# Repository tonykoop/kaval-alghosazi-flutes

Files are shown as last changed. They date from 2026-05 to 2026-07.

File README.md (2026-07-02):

# Kaval + Alghosazi Fipple Flutes

This repository is a prototype design packet for two related long fipple flutes. It is not build-ready for a final instrument until the P0 fipple-head and sound-window correction measurements below are recorded:

- a **Moldavian/Romanian-style fipple kaval** family, including 5-hole, 7-hole, two-piece, and double-drone options;
- a **fipple Alghosazi** family inspired by the Anasazi/Basketmaker long-flute lineage, with an easier fipple head and a rear thumb hole.

The head design intentionally borrows from Tony's `fujara` CAD: the player blows into an end mouth inlet, the air travels through a controlled internal flue, and sound is made at a side **true sound window** and splitting edge. The head is not copied from a commercial maker; it is a Tony-shop fujara/NAF hybrid that can be tuned and rebuilt.

## Build First

Start with these prototypes:

| Prototype | Why |
| --- | --- |
| `KAV-A3-5H` | Best first kaval: published 74 cm precedent, forgiving length, 5-hole pattern. |
| `ALG-AS3-J2` | Best first Alghosazi: published 82 cm two-piece precedent, thumb-hole layout. |
| `P0-FIPPLE-HEAD` | Scrap head tile that proves the mouth inlet, flue, window, and splitting edge before a full body. |

## File Map

| File | Use |
| --- | --- |
| `Kaval-Alghosazi-Design.xlsx` | Parametric workbook: family spec, formulas, hole schedules, fipple inputs. |
| `design.md` | Acoustic model, cultural/source notes, assumptions, and build intent. |
| `family-spec.csv` | Row-per-member design table used by drawing/CAD generators. |
| `hole-schedule.csv` | First-pass hole positions computed from labium-to-foot length (pre-P0; rerun after measured sound-window correction). |
| `bom.csv`, `sourcing.csv`, `cut-list.csv` | Procurement and stock prep. |
| `assembly-manual.md` | Shop sequence from fipple tile through tuning. |
| `docs/p0-fipple-head-measurement.md` | P0 fipple-head build and measurement procedure. |
| `sound-window-correction-log.csv` | Back-solve log for the measured fipple/sound-window correction. |
| `validation-loop.csv` | Prototype validation-loop scaffold with measurement-required gates. |
| `drawings/` | SVG manufacturing drawings and head/joint details. |
| `cad/` | OpenSCAD and SolidWorks starter handoff files. |
| `cnc/` | v4.2 operation plan and setup sheet. |
| `validation.csv` | Tuning and empirical correction log. |
| `capstone-deck.pptx`, `print-packet.pdf`, `site/index.html` | Presentation, shop print, and build-log deliverables. |
| `wolfram/kaval-alghosazi-flutes-wolfram-model.wl` | Existing acoustic model source; pending P0 measured correction. |
| `evolution/` | Evolution-pipeline Stage 0 intake: master manifest, design-intent, revision register (Gate A not yet run). |

## Status

**Status:** L1 concept packet

This is a first-pass engineering packet. Dimensions are parametric and source-backed where possible, but the fipple/sound-window correction is marked as a measured-prototype variable, not a borrowed NAF K2 correction.

Current readiness is `L1_packet`: fabrication drawings and schedules are starter artifacts, while the fipple/head correction, final hole locations, and production readiness remain measurement-required.

V5 migration status: `L1_packet`. Existing SVGs, OpenSCAD, CNC plans, renders, and print/site artifacts are registered in `visual-output-register.csv`; CAD/DXF authority, MCP provenance, sound-window correction, and measured tuning remain pending measurement.

## Attribution

The kaval references come from Moldavian/Romanian shepherd-flute practice; the Alghosazi references point toward Anasazi/Basketmaker flute replicas and contemporary adaptations. This packet is a modern shop design by Tony Koop, built with respect for those lineages and explicit source notes in `sources.md`.

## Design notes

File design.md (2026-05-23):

# Kaval + Alghosazi Fipple Flutes

**Packet ID:** KAV-ALG-FAM-001  
**Family:** open-pipe woodwind / duct-fipple flute  
**Pipeline:** cnc-lathe hybrid: split blank or deep bore, fipple head, lathe rounding, optional two-piece joint  
**Date:** 2026-05-06  
**Done-bar references:** `fujara`, `flutes`, `drone-flutes`, `pistalka`, `transverse-flute`

## Project Intent

Design a buildable family of long fipple kavals and Alghosazi flutes that feel close to the Fujara Flutes references while using Tony's existing fujara/flute workshop logic: parametric dimensions, a controllable fipple sound-window head, split-blank CNC or deep-bore construction, validation tables, and documented tuning loops.

The first physical goal is not a perfect production run. It is a controlled prototype ladder: prove the fipple head, build one A3 5-hole kaval, build one A#3 Alghosazi with a thumb hole, then decide whether the two-piece and double-drone versions deserve full CAD.

## Source And Scope

External reference pages checked:

- Fujara Flutes Kaval page: 5-hole fipple kavals, 7-hole expanded kavals, lengths from about 62-90 cm, and double Kaval/Kavalghoza drone concept.
- Fujara Flutes Alghosazi page: fipple adaptation of Anasazi-style flute, top hole moved to the back as a thumb hole, lengths from about 70-85 cm, and a double-drone option.
- Flutopedia Anasazi tuning notes: used only to justify the Alghosazi starter offset set as an Anasazi-derived primary sequence.

Local source artifacts inspected:

- `fujara/design-table/fujara_equations.md` and SolidWorks dimension extracts for fipple/flue plug geometry.
- `drone-flutes/design.md` and `flutes/skills/parametric-design-table.md` for open-pipe, shop, and validation workflow.
- `pistalka/docs/build-packet/design.md` for a compact fipple-flute build sequence.

## Governing Model

These flutes are modeled as **open-open cylindrical fipple flutes** with a non-NAF fujara-style sound-window end correction.

```text
f = c / (2 * L_eff)
c = 13552 in/s at about 68 F
L_eff = physical_labium_to_foot + foot_end_correction + sound_window_correction
foot_end_correction ~= 0.6 * bore_radius
sound_window_correction = measured prototype value, not Tony's NAF K2 table
```

For first-pass hole placement, the packet uses a proportional open-pipe layout:

```text
x_from_labium = labium_to_foot * 2^(-semitone_offset / 12)
x_from_foot = labium_to_foot - x_from_labium
```

The hole schedule is intentionally a **starter drill schedule**. The builder drills undersized, tunes the root by trimming the foot, then opens each hole upward by careful reaming/undercutting. If a hole goes sharp, the recovery is wax test, bushing, or a rebuilt body.

`family-spec.csv` includes `estimated_sound_window_correction_in`. Positive values mean the fipple/window system or added acoustic path must make the instrument behave longer than the visible labium-to-foot length. Negative values mean the source-observed body length is overlong for the nominal root under a simple open-pipe model; treat those as overlength blanks to trim or as evidence that the commercial key naming may not equal the all-closed root.

The first-pass schedules do not yet include a measured sound-window correction. Back-solve it after P0 with:

```text
L_eff_measured = c / (2 * measured_root_hz)
sound_window_correction = L_eff_measured - labium_to_foot - foot_end_correction
foot_end_correction ~= 0.6 * bore_radius
```

Record the result in `sound-window-correction-log.csv`. Only then update `Kaval-Alghosazi-Design.xlsx`, `family-spec.csv`, and the hole schedules.

## Scale Plans

### 5-Hole Fipple Kaval

The 5-hole kaval follows the published C-reference pitch set:

```text
0, +2, +3, +6, +7, +8 semitones
Example in C: C D D# F# G G#
```

### 7-Hole Fipple Kaval

The expanded kaval adds the two half-step options described by the reference page:

```text
0, +2, +3, +4, +6, +7, +8, +9 semitones
Example in C: C D D# E F# G G# A
```

### Alghosazi

The Alghosazi starter scale uses an Anasazi-derived primary sequence. The top hole is placed on the back as a thumb hole, matching the design note from the reference page.

```text
0, +2, +4, +7, +9, +11, +12 semitones
Example in A#: A# C D F G A A#
```

This is marked as a musical-design assumption. If Tony wants a different Alghosazi mode after listening to examples, change the offsets in `Kaval-Alghosazi-Design.xlsx` and regenerate `hole-schedule.csv`.

## Fujara-Style Fipple Head

The requested head architecture is:

```text
mouth at end -> rectangular inlet -> internal windway/flue -> side true sound window -> splitting edge -> main bore
```

Starter dimensions:

| Feature | Kaval Starter | Alghosazi Starter | Notes |
| --- | ---: | ---: | --- |
| Top end to true window datum | 1.45-1.65 in | 1.65-1.80 in | Adjust for comfort and joint location. |
| Windway height | 0.033-0.045 in | 0.035-0.048 in | Start with removable flue plug trials. |
| Windway width | 0.45-0.55 in | 0.45-0.58 in | About 55-65 percent of bore. |
| Window length | 0.25-0.38 in | 0.28-0.42 in | Widen/lengthen only after tone test. |
| Splitting edge offset KPI | 0.005-0.015 in | 0.005-0.015 in | Borrowed from Tony's fujara canary, not a final law. |
| Plug fit | wax-sealed slip | wax-sealed slip | Removable until final voicing. |

### P0 Measurement Loop

Build `P0-FIPPLE-HEAD` before a full flute body. Use scrap stock or a short half-bore test channel matching the selected bore, cut the end mouth inlet, test removable plug shims at 0.033, 0.038, and 0.045 in, and vary only one window or splitting-edge parameter between trials.

For each speaking trial, log the measured windway height, window length, window width, splitting-edge offset, blow-pressure note, temperature/RH, measured root pitch, and whether the tone chokes, overblows, or stabilizes. The geometry stays inferred until that log exists.

## Two-Piece And Double Options

The two-piece option is a **shop convenience and tuning risk**, not a decorative afterthought. Use it only after a solid prototype speaks well.

- Tenon engagement: 1.25 in minimum.
- Cork compression: fit by sanding; no forced assembly.
- Joint location: avoid placing the joint within 0.75 in of a tone hole.
- Bore step: less than 0.005 in at the joint after final sanding.
- Ferrule: recommended for A/A# bodies and double-flute assemblies.

Double-drone versions are documented in `double-drone-spec.csv` and `drawings/double-drone-layout.svg`. Each side gets its own windway so the melody flute can be played alone and the drone can be tuned independently.

## Family Table

See `family-spec.csv` for the source of truth. The core starter members are:

| Member | Role |
| --- | --- |
| `KAV-A3-5H` | First kaval prototype. |
| `KAV-AS3-7H` | Two-piece expanded kaval prototype. |
| `ALG-AS3-J2` | First Alghosazi prototype. |
| `ALG-A3-J3` | Three-piece Alghosazi joint stress test. |

## Manufacturing Path

Preferred path for the first two prototypes:

1. Make a removable fipple-head test tile from scrap.
2. Record the speaking head settings and back-solve the sound-window correction in `sound-window-correction-log.csv`.
3. Build a split-blank body so the bore, windway, and window are visible and correctable.
4. Glue and turn only after the fipple speaks.
5. Drill holes undersized from a laser/CNC template or V-block setup.
6. Tune root first, then holes from foot upward.
7. Record measurements in `validation.csv` and `validation-loop.csv`, then update the next prototype.

Deep-bore drilling is allowed for later solid-body builds. Use the skill reference `headstock-driven-deep-bore-drilling.md` before attempting a long solid blank.

## Assumptions

- A4 = 440 Hz.
- 68 F speed-of-sound baseline.
- Website lengths are used as precedent dimensions, not guaranteed acoustic formulas.
- Alghosazi tuning is a starter interpretation based on contemporary Anasazi-tuned six-hole practice.
- Tone hole positions ignore final hole-diameter perturbation until measured prototype data exists.
- The fipple head is Tony's derived design and must be validated by physical tests.
- The P0 correction is unknown until measured; do not promote this packet above `L1_packet` from source observations alone.

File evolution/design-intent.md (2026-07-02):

# Design Intent — kaval-alghosazi-flutes rev A

- Master CAD: `cad/kaval_alghosazi_master.scad` (sha256: c42d454dca177201263adffe5e6119c1dd6b02e1e94f62a42d3a19850f0d5d58) + `cad/kaval_alghosazi_body.scad` (sha256: 21786146c1ea73cd9707182d0e88491040a9f89159951d2f006b13d59cee006a), driven by `Kaval-Alghosazi-Design.xlsx` (sha256: e3fb7870a6145c4f49f438ee006fb4e052e1e944b8448978cd7332c4566e9df4)
- Function: A family of long duct/fipple flutes — a Moldavian/Romanian-style fipple kaval (5-hole, 7-hole, two-piece, double-drone variants) and a fipple Alghosazi (Anasazi/Basketmaker-lineage-inspired, rear thumb hole). The head is a Tony-shop fujara/NAF hybrid fipple (end mouth inlet, internal flue, side true sound window + splitting edge), not a copy of a commercial maker's head.
- Environment: hand-held wind instrument; long solid or split-blank wooden body; fipple/flue plug is removable and wax-sealed for voicing iteration.
- Target qty: prototype ladder — one A3 5-hole kaval, then one A#3 Alghosazi with thumb hole, before deciding on two-piece/double-drone variants. Deadline: TBD. Budget/unit ceiling: TBD.

## Critical dimensions (carry tolerances)

| Feature | Nominal | Tolerance | Why critical | Source |
| --- | --- | --- | --- | --- |
| Fipple/sound-window correction | unknown | build P0-FIPPLE-HEAD, compare root prediction vs measured (risks.md Acoustic) | governs all downstream hole positions | sound-window-correction-log.csv (measurement_required) |
| Hole positions (kaval/Alghosazi) | first-pass proportional | drill undersized, record before/after cents per hole (validation.csv) | intonation | hole-schedule.csv / family-spec.csv (measurement_required) |
| Bore-wander tolerance | ≤ 0.050 in exit offset | bore scrap first and measure; switch to split-blank CNC if exceeded (risks.md Structural) | wall integrity | risks.md (measurement_required) |
| Windway height | 0.033-0.045 in (trial range) | voicing iteration on removable plug (bom.csv BOM-002) | attack/tone | bom.csv (measurement_required) |
| Alghosazi thumb hole placement | mark with tape, air-grip test | drill undersized before final (risks.md Ergonomic) | playability/ergonomics | risks.md (measurement_required) |

## Incidental (free for DFM)

- Exterior finish (shellac/oil/wax), ferrule material choice (brass vs. hardwood), cosmetic body shaping outside bore/fipple/hole geometry.

## Must-nots (DFM may never violate)

- Do not finalize hole locations before P0 fipple-head sound-window correction is measured and logged (design.md Project Intent; sound-window-correction-log.csv).
- Do not apply heavy finish to the windway or splitting edge — mask both and recheck attack after cure (risks.md Fit And Finish).
- Do not choose ferrule dimensions before the body OD is turned (risks.md Supply).
- Do not commit to elder/locust stock length/scale without verifying supplier stock first; use ash/maple/cherry for prototypes instead (risks.md Supply).
- Do not drill final tone-hole or thumb-hole diameters directly — undersize and tune/fit-test incrementally (risks.md Acoustic/Ergonomic).

## Material intent

- Preferred: straight-grain elder, locust, ash, maple, cherry, or walnut body blank (bom.csv BOM-001).
- Acceptable subs: ash/maple/cherry for prototypes if elder/locust supply is constrained (risks.md Supply).
- Forbidden: none recorded beyond the prototype-before-final-stock sequencing above.

## Stage status

Stage 0 intake complete 2026-07-01. Gate A (Alpha shop compile) NOT yet run — no concessions logged, nothing presented as shippable. Packet stays L1_packet per README until P0 fipple-head and sound-window correction measurements exist.

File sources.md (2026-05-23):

# Sources And Provenance

## External Pages Checked

- Fujara Flutes Kaval page: https://www.fujaraflutes.com/moldavian-kaval-flutes
- Fujara Flutes Alghosazi page: https://www.fujaraflutes.com/alghosazi
- Flutopedia Native American flute tunings / Anasazi note: https://www.flutopedia.com/naf_tunings.htm

## Local Sources Used

- `../fujara/README.md`
- `../fujara/design-table/fujara_equations.md`
- `../fujara/CAD/fujara-body/G2Fujara_Assembly.SLDASM_dimensions.csv`
- `../drone-flutes/design.md`
- `../flutes/skills/parametric-design-table.md`
- `../pistalka/docs/build-packet/design.md`

## Source-Backed Facts Used

- The kaval reference page presents fipple-style kavals and gives 5-hole and 7-hole pitch sets.
- The same page documents examples in G#, A, B, C and a double Kaval/Kavalghoza drone concept.
- The Alghosazi reference page frames the instrument as an easier fipple adaptation of an Anasazi-style flute and notes the rear thumb-hole idea.
- Tony's fujara CAD records a fipple/flue plug system with narrow windway, removable plug logic, and splitting-edge KPI values.

## Assumptions Needing Prototype Data

- Exact fipple sound-window end correction.
- Measured P0 windway/window/splitting-edge setting that speaks without choking.
- Final hole diameters and undercutting.
- Alghosazi mode preference after listening/playing.
- Joint effect on tuning and response.

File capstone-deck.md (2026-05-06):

# Kaval + Alghosazi Fipple Flutes Capstone
- Musical instrument documentation capstone
- Build packet: kaval-alghosazi-flutes
- Generated: 2026-05-05

---

# Project Intent
- Design a buildable family of long fipple kavals and Alghosazi flutes that feel close to the Fujara Flutes references while using Tony's existing fujara/flute workshop logic: parametric dimensions, a controllable fipple sound-window head, split-blank CNC or deep-bore construction, validation tables, and documented tuning loops.

_Speaker notes:_ Read design.md before committing to dimensions or sourcing decisions.

---

# Physics Model
- These flutes are modeled as **open-open cylindrical fipple flutes** with a non-NAF fujara-style sound-window end correction.

```
f = c / (2 * L_eff)
c = 13552 in/s at about 68 F
L_eff = physical_labium_to_foot + foot_end_correction + sound_window_correction
foot_end_correction ~= 0.6 * bore_radius
sound_window_correction = measured prototype value, not Tony's NAF K2 table
```

```
x_from_labium = labium_to_foot * 2^(-semitone_offset / 12)
x_from_foot = labium_to_foot - x_from_labium
```

_Speaker notes:_ Governing equations extracted verbatim from design.md. Apply empirical corrections (NAF K2, scale offsets) only where the model permits — see references/acoustic-models.md.

---

# How To Use This Packet
- Start with design.md for intent and assumptions.
- Use bom.csv, sourcing.csv, and cut-list.csv before buying or cutting.
- Use drawing-brief.md and CAD/CNC folders before machining.
- Print the packet for shopping, shop work, and validation.

---

# File Map
- design.md: Project intent, catalog metadata, assumptions, and validation plan.
- bom.csv: Starter bill of materials with part categories, quantities, drawing refs, and notes.
- sourcing.csv: Supplier/search tracker with specs, price/date fields, lead time, substitutes, and risks.
- cut-list.csv: Rough/final stock sizes, material, grain/orientation, operations, yield, and offcuts.
- drawing-brief.md: Manufacturing drawing and technical product sketch brief.
- assembly-manual.md: Shop-facing sequence, tools, fixtures, safety, tuning, finishing, and maintenance notes.
- validation.csv: Target/measured values, tolerance, environment, result, and tuning/build action log.
- supplier-rfq.md: Supplier email/request-for-quote starter.

---

# Family Spec

| member_id | instrument | subtype | target_note | target_hz | midi | scale_label | hole_count | hole_offsets_st | bore_id_in | body_od_in | wall_in | total_length_cm | total_length_in | top_to_window_in | labium_to_foot_in | open_pipe_leff_in | estimated_sound_window_correction_in | tuning_delta_interpretation | chamber_to_bore | wood_species | construction | source_basis | done_bar_ref | notes |
| --- | --- | --- | --- | --- | --- | --- | --- | --- | --- | --- | --- | --- | --- | --- | --- | --- | --- | --- | --- | --- | --- | --- | --- | --- |
| KAV-GS3-5H | Fipple Kaval | 5-hole Moldavian/Romanian | G#3 | 207.652 | 56 | Kaval gypsy mode: 0,2,3,6,7,8 semitones | 5 | 2 3 6 7 8 | 0.8750 | 1.3750 | 0.2500 | 79.0 | 31.102 | 1.600 | 29.502 | 32.631 | 3.129 | positive: needs fipple/window end correction or added acoustic length | 33.7 | Locust or elder | solid or split blank; optional two-piece joint | Fujara Flutes observed G# kaval length 79 cm | fujara + flutes + pistalka | Longest 5-hole starter; use as low-voice reference. |
| KAV-A3-5H | Fipple Kaval | 5-hole Moldavian/Romanian | A3 | 220.000 | 57 | Kaval gypsy mode: 0,2,3,6,7,8 semitones | 5 | 2 3 6 7 8 | 0.8750 | 1.3750 | 0.2500 | 74.0 | 29.134 | 1.600 | 27.534 | 30.800 | 3.266 | positive: needs fipple/window end correction or added acoustic length | 31.5 | Elder | two-piece optional hand-cut joint | Fujara Flutes observed A kaval length 74 cm | fujara + flutes + pistalka | Recommended first kaval because length, bore, and hand span are forgiving. |
| KAV-B3-5H | Fipple Kaval | 5-hole Moldavian/Romanian | B3 | 246.942 | 59 | Kaval gypsy mode: 0,2,3,6,7,8 semitones | 5 | 2 3 6 7 8 | 0.8125 | 1.3125 | 0.2500 | 67.0 | 26.378 | 1.500 | 24.878 | 27.440 | 2.562 | positive: needs fipple/window end correction or added acoustic length | 30.6 | Elder | solid split blank | Fujara Flutes observed B kaval length 67 cm | fujara + flutes + pistalka | Compact 5-hole version; tighter fipple tolerances. |
| KAV-C4-5H | Fipple Kaval | 5-hole Moldavian/Romanian | C4 | 261.626 | 60 | Kaval gypsy mode: 0,2,3,6,7,8 semitones | 5 | 2 3 6 7 8 | 0.7500 | 1.2500 | 0.2500 | 62.0 | 24.409 | 1.450 | 22.959 | 25.900 | 2.940 | positive: needs fipple/window end correction or added acoustic length | 30.6 | Elder, maple, or cherry | solid split blank | Fujara Flutes observed C kaval length 62 cm | fujara + flutes + pistalka | Smallest 5-hole kaval; good for fipple/head trials. |
| KAV-A3-7H | Fipple Kaval | 7-hole expanded Moldavian | A3 | 220.000 | 57 | Expanded kaval: 0,2,3,4,6,7,8,9 semitones | 7 | 2 3 4 6 7 8 9 | 0.8750 | 1.4000 | 0.2625 | 90.0 | 35.433 | 1.650 | 33.783 | 30.800 | -2.983 | negative: observed source length is overlong for this nominal root; trim foot or reassess key naming | 38.6 | Elder | solid split blank | Fujara Flutes observed 7-hole A kaval length 90 cm | fujara + flutes + pistalka | Expanded note set; lower holes may be covered with finger bases. |
| KAV-AS3-7H | Fipple Kaval | 7-hole expanded Moldavian | A#3 | 233.082 | 58 | Expanded kaval: 0,2,3,4,6,7,8,9 semitones | 7 | 2 3 4 6 7 8 9 | 0.8750 | 1.4000 | 0.2625 | 85.0 | 33.465 | 1.650 | 31.815 | 29.071 | -2.743 | negative: observed source length is overlong for this nominal root; trim foot or reassess key naming | 36.4 | Dogwood or elder | two-piece optional hand-cut joint | Fujara Flutes observed 7-hole A# kaval length 85 cm | fujara + flutes + pistalka | Good two-piece test because the published example is collapsible. |
| KAV-B3-7H | Fipple Kaval | 7-hole expanded Moldavian | B3 | 246.942 | 59 | Expanded kaval: 0,2,3,4,6,7,8,9 semitones | 7 | 2 3 4 6 7 8 9 | 0.8125 | 1.3125 | 0.2500 | 69.0 | 27.165 | 1.500 | 25.665 | 27.440 | 1.774 | positive: needs fipple/window end correction or added acoustic length | 31.6 | Elder | solid split blank | Fujara Flutes observed 7-hole B kaval length 69 cm | fujara + flutes + pistalka | Compact 7-hole version; validate hand position before final hole diameters. |
| ALG-AS3-J2 | Fipple Alghosazi | Anasazi-derived with thumb hole | A#3 | 233.082 | 58 | Anasazi-derived: 0,2,4,7,9,11,12 semitones | 6 | 2 4 7 9 11 12 | 0.8750 | 1.3750 | 0.2500 | 82.0 | 32.283 | 1.800 | 30.483 | 29.071 | -1.412 | negative: observed source length is overlong for this nominal root; trim foot or reassess key naming | 34.8 | Ash | two-piece hand-cut joint | Fujara Flutes observed A# Alghosazi length 82 cm | fujara + flutes + pistalka | Recommended first Alghosazi; published example uses a collapsible joint. |
| ALG-AS3-SOLID | Fipple Alghosazi | Anasazi-derived with thumb hole | A#3 | 233.082 | 58 | Anasazi-derived: 0,2,4,7,9,11,12 semitones | 6 | 2 4 7 9 11 12 | 0.8750 | 1.3750 | 0.2500 | 85.0 | 33.465 | 1.800 | 31.665 | 29.071 | -2.593 | negative: observed source length is overlong for this nominal root; trim foot or reassess key naming | 36.2 | Locust | solid split blank | Fujara Flutes observed solid A# Alghosazi length 85 cm | fujara + flutes + pistalka | Solid-body alternate for comparing joint vs no-joint response. |
| ALG-A3-J3 | Fipple Alghosazi | Anasazi-derived with thumb hole | A3 | 220.000 | 57 | Anasazi-derived: 0,2,4,7,9,11,12 semitones | 6 | 2 4 7 9 11 12 | 0.8750 | 1.3750 | 0.2500 | 73.0 | 28.740 | 1.750 | 26.990 | 30.800 | 3.810 | positive: needs fipple/window end correction or added acoustic length | 30.8 | Oak | three-piece hand-cut joint | Fujara Flutes observed A Alghosazi length 73 cm | fujara + flutes + pistalka | Use as the modular joint stress test. |
| ALG-B3-SOLID | Fipple Alghosazi | Anasazi-derived with thumb hole | B3 | 246.942 | 59 | Anasazi-derived: 0,2,4,7,9,11,12 semitones | 6 | 2 4 7 9 11 12 | 0.8125 | 1.3125 | 0.2500 | 70.0 | 27.559 | 1.650 | 25.909 | 27.440 | 1.531 | positive: needs fipple/window end correction or added acoustic length | 31.9 | Elder or maple | solid split blank | Fujara Flutes observed B Alghosazi length 70 cm | fujara + flutes + pistalka | Compact Alghosazi; top thumb hole needs ergonomic mockup. |

_Speaker notes:_ Sizes scale via the master scale factor; tuning targets are first-order Helmholtz/cantilever predictions to be empirically corrected per prototype.

---

# Build Workflow
- Design and assumptions
- Source materials and hardware
- Prepare stock, fixtures, and CNC/laser/lathe setup
- Assemble, tune, finish, and validate

---

# Sourcing And BOM
- BOM gives part categories and drawing references.
- Sourcing tracks search terms, supplier candidates, price/date, lead time, substitutions.
- Visual BOM brief turns the parts list into a presentation-ready image board.

---

# Shop Packet
- Cut list for lumber/sheet/blank planning.
- Assembly manual for away-from-keyboard work.
- Validation sheet for measured dimensions, tuning, pass/fail checks.

---

# Drawings, CAD, CNC
- drawing-brief.md defines required views, dimensions, datums, sketch intent.
- cad/ holds models and design tables.
- cnc/ holds CAM, toolpaths, setup sheets, dry-run notes.
- drawings/ holds PDFs, SVGs, DXFs, drawing exports.






---

# Images And Screenshots
- images/hero.png

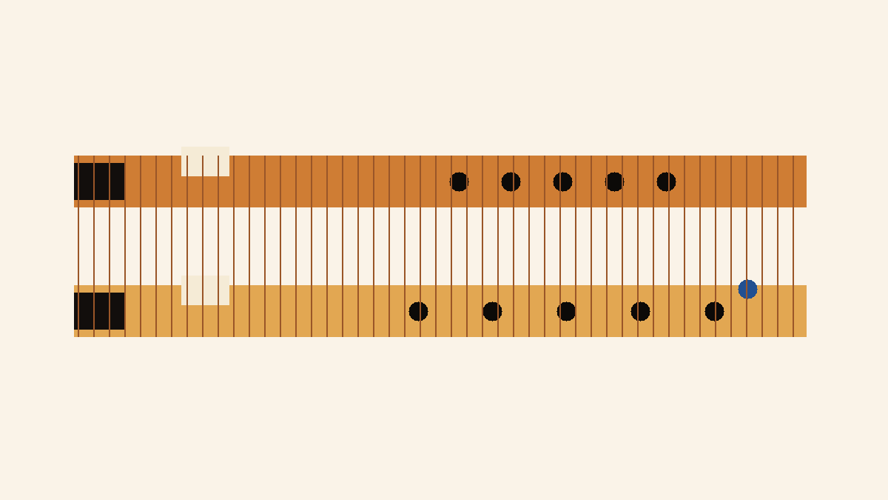
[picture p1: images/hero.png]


---

# Validation Plan
- A4 = 440 Hz reference check.
- Tuning targets logged in validation.csv.
- Critical dimensions verified against design sheet and CAD.
- Photos and revision notes after each major step.

---

# Open Risks / Decisions
- TBDs in design sheet and BOM.
- Supplier price/availability not yet verified.
- Generated images marked as concept placeholders.
- Empirical corrections await measured prototype data.

---

# Next Actions
- Replace TBDs with measured/source-backed values.
- Verify live supplier price and availability before buying.
- Export final drawings and visual BOM images.
- Regenerate this deck and print packet after final edits.

---

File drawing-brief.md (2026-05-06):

# Drawing Brief

## Required Views

- Family overview: each member as a scaled open-pipe body with bore ID and total length.
- Hole layout: kaval and Alghosazi separate, measured from labium and from foot.
- Fipple head section: end mouth inlet, windway, flue plug, true sound window, splitting edge, bore.
- Two-piece joint section: tenon, socket, cork wrap, ferrule/collar, bore continuity.
- Double-drone layout: two bores, independent windways, melody side, drone side, thumb vent.

## Datums

- Datum A: labium/splitting-edge plane.
- Datum B: tuned foot end.
- Datum C: bore centerline.
- Datum D: back thumb-hole centerline for Alghosazi.

## Tolerances

- Bore ID: +/-0.005 in after reaming/lapping.
- Hole center: +/-0.020 in before tuning; final pitch matters more than nominal center.
- Windway height: +/-0.002 in once a plug speaks.
- Joint bore step: less than 0.005 in.
- Noncritical exterior: +/-0.030 in.

## Drawing Outputs

Generated SVGs live in `drawings/`. Build-critical dimensions come from `Kaval-Alghosazi-Design.xlsx`, `family-spec.csv`, and `hole-schedule.csv`, not from raster images.

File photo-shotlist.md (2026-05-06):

# Photo Shotlist

Follow the repo-level photo pipeline style: real process photos replace concept placeholders as soon as shop work begins.

## P0 Fipple Head

- End mouth inlet before plug install.
- Removable flue plugs with shim labels.
- Side true sound window and splitting edge closeup.
- Tuner screenshot or phone photo during first tone.

## P1 Bodies

- Blank selection with grain orientation marked.
- Split blank or deep-bore setup.
- Routed/bored bore before glue-up.
- Hole template wrapped around body.
- First drilled undersized hole.
- Final tuned flute full length.

## Jointed/Double Options

- Tenon/socket before cork.
- Cork/ferrule fit closeup.
- Double-body temporary clamp test.
- Independent windways at the mouth end.

## Finished Portfolio

- Kaval and Alghosazi side by side.
- Player hand reach shot.
- Fipple head detail.
- Validation/tuning bench shot.

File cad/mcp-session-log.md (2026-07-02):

# Kaval + Alghosazi Flutes MCP Session Log

Current status: no MCP, CAD, DXF, render, CAM, or measurement sessions were run
or verified in this V5 migration lane.

This log is a provenance stub for future V5 work. Existing packet content is
grounded in `README.md`, `design.md`, `family-spec.csv`, the hole schedules,
`docs/p0-fipple-head-measurement.md`, `docs/sound-window-correction-model.md`,
and the validation logs. This file does not claim that native CAD, measured
sound-window correction, measured tuning, or CAM-ready toolpaths already exist.

| timestamp_utc | tool | session_id | artifact | parent_artifact | role | authority | notes |
| --- | --- | --- | --- | --- | --- | --- | --- |
| TBD | SolidWorks MCP | TBD | native CAD layout | `cad/SolidWorks-MasterLayout-Plan.md`; `cad/design-table-inputs.csv` | native CAD master | pending_measurement | Future session must preserve fipple-head and hole-position measurement gates. |
| TBD | OpenSCAD review | TBD | `cad/kaval_alghosazi_master.scad` | `family-spec.csv`; `hole-schedule.csv`; `cad/design-table-inputs.csv` | parametric CAD starter | pending_measurement | Existing OpenSCAD is not native CAD or CAM authority. |
| TBD | DXF export | TBD | hole and body templates under `drawings/` | reviewed CAD/table source | fabrication template | pending_measurement | Future DXF exports must wait for measured sound-window correction and reviewed hole schedules. |
| TBD | CNC/CAM review | TBD | shop toolpaths | `cnc/cnc-plan.json`; reviewed CAD/DXF | CAM setup | pending_measurement | Current CNC files are operation plans only, not G-code or release-ready toolpaths. |
| TBD | Wolfram/acoustic analysis | TBD | corrected acoustic model | `docs/sound-window-correction-model.md`; measured `sound-window-correction-log.csv` | acoustic validation | pending_measurement | Model estimates are not cut authority until P0 measurement exists. |
| TBD | Camera/render tool | TBD | `images/hero.png` or replacement render | reviewed CAD or concept brief | visual support | concept_only | Visuals must not control fipple geometry, bore, hole centers, or tuning. |
| 2026-07-01 | claude-code (Fable 5) + OpenSCAD CLI | fable-v5-refresh-2026-07-01 | `cad/kaval_alghosazi_master.scad`; `cad/kaval_alghosazi_body.scad` | `family-spec.csv`; `hole-schedule.csv`; `cad/design-table-inputs.csv` | packet_refresh (render check only) | pending_measurement | Both existing OpenSCAD starters kept as-is (no rewrite). Render check: pass for both (openscad -o STL, exit 0). README status line normalized from prose-only "## Status" section to a proper `**Status:**` line (L1 concept packet, no level change); evolution/ Stage 0 intake added. |

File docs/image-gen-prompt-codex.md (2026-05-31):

# Image Generation Prompt

Concept visualization only. Do not treat generated images as dimensional, tuning, CAD, DXF, or fabrication authority.

## Hero Prompt

Photorealistic studio product photograph of two related long fipple flute prototypes: a Moldavian/Romanian-style fipple kaval with five front holes and a fipple Alghosazi with six holes plus a rear thumb-hole indication, both using Tony's fujara/NAF hybrid fipple head with an end mouth inlet, internal windway, side true sound window, and splitting edge. Warm straight-grain wood, optional two-piece joint on one body, clean studio background, soft directional lighting, three-quarter product angle, about a 50mm lens, high detail.

## In-Context Prompt

Photorealistic workshop scene showing the kaval and Alghosazi prototypes beside a removable P0 fipple-head test tile, plug shims, a tuner, and hole templates. Natural light, tidy bench, the long bodies and side sound-window heads visible, environmental storytelling about measuring the sound-window correction before full production.

## Detail/Macro Prompt

Macro close-up of the fujara-style fipple head used on the kaval/Alghosazi: end mouth inlet, smooth internal windway exit, side true sound window, crisp splitting edge, removable plug fit, wax-sealed trial shims nearby, warm wood grain, photorealistic high detail.

## Negative / Avoid

Avoid logos, watermarks, readable text, recorder beak mouthpieces, generic panpipes, impossible hole patterns, extra drones unless clearly separate, distorted hands, and false measured labels.

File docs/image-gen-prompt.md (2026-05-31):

# Image-Gen Prompts

Concept image only; not fabrication authority. Do not include cut-ready dimensions, hole locations, or toolpaths.

## Hero Prompt

A long slender wooden fipple flute presented as a finished physical instrument, laid at a clean 3/4 product-photography angle on a neutral light-gray studio sweep. It is a turned cylindrical open-pipe woodwind roughly two and a half feet long, lathe-rounded with a smooth satin oil finish that lets the warm grain of a pale European hardwood (elder or maple) show through. The recognizable feature is a fujara-style fipple head at the top end: the player blows into an end mouth inlet, and a side true sound window with a crisp splitting edge is cut into the body a short way down from the cap, the signature mark of this duct-fipple design. A short row of round tone holes runs along the front of the lower body. The bore is a single clean cylinder of even diameter. Soft directional studio light rakes from upper left, modeling the cylindrical surface and casting a soft shadow. ~50mm lens, shallow but controlled depth of field, photorealistic, high detail, no text labels, no maker marks.

## In-Context Prompt

The kaval and Alghosazi fipple flutes staged on a maker's workbench in a small woodworking shop, soft natural window light from the side, with curls of wood shaving, a few hand tools, and a length of split-blank stock blurred in the background. One flute rests on a felt-lined cradle while a second leans against a vise; the warm satin-oiled hardwood bodies glow against the muted shop tones. Environmental storytelling of a one-off prototype build, shallow depth of field, concept visualization only, photorealistic, no text or signage.

## Detail Prompt

Macro close-up of the fujara-style fipple head: the end mouth inlet at the very top, the turned cap and internal windway implied, and just below it on the side of the body the rectangular true sound window with its sharp splitting edge where the air column is excited. Raking low-angle light grazes across the window opening and splitting edge to reveal the crisp cut and the fine grain and satin finish of the pale hardwood. Extremely high detail on the wood texture and the clean edge geometry, no measurements, no callout lines, no text.

## Negative / Avoid

No text, logos, watermarks, or fake maker marks; no dimension callouts, leader lines, or measurement numbers; no impossible or fantasy mechanisms, no metal keywork (these are open-hole flutes); anatomically plausible hands if a player is shown.

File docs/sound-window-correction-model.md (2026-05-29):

# Sound-Window Correction — Acoustic Back-Solve Model

Status: L1 model estimate. No physical P0 measurement has been performed yet.
All corrections below are first-order analytical values. The P0 fipple-head
measurement must be completed before any hole position is considered authoritative.

## Purpose

The side sound-window and splitting edge of a fipple flute create an acoustic
end-correction that shifts the effective length of the air column away from the
physical labium-to-foot distance. This correction must be measured at P0 and
applied to the hole-schedule before drilling.

## Model

For an open-open cylindrical fipple flute, the effective length is:

```
L_eff = c / (2 × f_root)
```

where:
- `c` = speed of sound at lab conditions ≈ 345,400 mm/s at 22 °C (13,598 in/s)
- `f_root` = measured root pitch in Hz (tuner capture at P0)

The total effective length is composed of:

```
L_eff = labium_to_foot + sound_window_correction + foot_end_correction
```

Rearranging to back-solve the sound-window correction:

```
sound_window_correction = L_eff - labium_to_foot - foot_end_correction
```

The foot end-correction for an unflanged open end:

```
foot_end_correction ≈ 0.6 × bore_radius
```

## Model Estimates (pending P0 measurement)

These are **pre-P0 estimates only**. Do not use for cutting. Record the
measured back-solve in `sound-window-correction-log.csv` after the P0 build.

Sound speed at 22 °C / 345.4 m/s = 13,598 in/s = 345,400 mm/s.

### KAV-A3-5H (kaval, A3 root, 5-hole)

| Parameter | Value | Source |
| --- | --- | --- |
| Target root | A3 = 220.000 Hz | family-spec.csv |
| Bore ID | 0.875 in = 22.23 mm | Kaval-Alghosazi-Design.xlsx |
| Bore radius | 11.11 mm | derived |
| L_eff at 220 Hz | 345,400 / (2 × 220) = 785.0 mm | model estimate |
| Foot end-correction | 0.6 × 11.11 = 6.7 mm | standard approximation |
| Labium-to-foot (nominal) | ~735 mm | workbook estimate — measurement required |
| **Model sound-window correction** | **785.0 − 735 − 6.7 ≈ +43 mm** | **model estimate — pending P0** |

**Acoustic honesty caveat:** The labium-to-foot distance is a workbook estimate
from source references. The actual P0-measured value may differ by ±10 mm or
more depending on fipple-head geometry and plug setting. The model correction
of +43 mm is a **starting reference only**, not a dimensional authority.

### ALG-AS3-J2 (alghosazi, A#3 root, two-piece, 6-hole)

| Parameter | Value | Source |
| --- | --- | --- |
| Target root | A#3 = 233.082 Hz | family-spec.csv |
| Bore ID | 0.875 in = 22.23 mm | Kaval-Alghosazi-Design.xlsx |
| Bore radius | 11.11 mm | derived |
| L_eff at 233.082 Hz | 345,400 / (2 × 233.082) = 741.2 mm | model estimate |
| Foot end-correction | 0.6 × 11.11 = 6.7 mm | standard approximation |
| Labium-to-foot (nominal) | ~690 mm | workbook estimate — measurement required |
| **Model sound-window correction** | **741.2 − 690 − 6.7 ≈ +44.5 mm** | **model estimate — pending P0** |

**Acoustic honesty caveat:** Same as KAV-A3-5H above. All values are
analytical estimates; the P0 measurement log drives actual hole positions.

## Hole-Schedule Update Rule

If the back-solved P0 correction shifts any hole center by more than 2.5 mm
(0.100 in), regenerate the hole-schedule(s) from the corrected labium-to-foot
before marking any column `measured`.

The `effective_length_correction_mm` column in `hole-schedule.csv`,
`kaval-hole-schedule.csv`, and `alghosazi-hole-schedule.csv` holds the
correction applied for the row's geometry. Until P0 is complete, all values
in that column are `pending_measurement`.

## Reference

- Fletcher and Rossing, *Physics of Musical Instruments*, §16.2 — end corrections
  for open cylindrical pipes.
- Benade, *Fundamentals of Musical Acoustics*, §21.2 — fipple and labium
  end-correction discussion.
- `docs/p0-fipple-head-measurement.md` — measurement procedure and P0 pass criteria.
- `sound-window-correction-log.csv` — back-solve log to fill after P0 build.

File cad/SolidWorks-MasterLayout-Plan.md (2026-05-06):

# SolidWorks Master Layout Plan

## Master Sketch

- `g_body_L_total`
- `g_labium_to_foot`
- `g_top_to_window`
- `g_bore_ID`
- `g_body_OD`
- `g_wall`
- `g_windway_height`
- `g_windway_width`
- `g_window_length`
- `g_window_width`
- `g_splitting_edge_offset`
- `g_joint_tenon_length`
- `g_joint_cork_allowance`

## Configurations

Use `cad/design-table-inputs.csv` as the row-per-member design table. Each configuration should suppress or enable:

- 5-hole vs 7-hole pattern.
- Alghosazi back thumb hole.
- Solid vs jointed body.
- Double-drone assembly reference geometry.

## Critical CAD Checks

- Bore centerline stays continuous across joint.
- Hole center coordinates match `hole-schedule.csv`.
- Windway height is equation-driven, not a sketch accident.
- Splitting-edge offset is measured as a driven KPI.

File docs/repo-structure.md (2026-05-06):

# Repository Structure

This is a root-level project-repo packet with build-packet artifacts at the top level, matching Tony's existing `drone-flutes`, `gemshorn`, and `transverse-flute` style.

Generated directories:

- `cad/` - OpenSCAD, SolidWorks design table inputs, global variables.
- `cnc/` - v4.2 pre-CAM operation plan.
- `data/` - guided intake and source observations.
- `drawings/` - manufacturing SVG drawings.
- `images/` - concept placeholder and future build photos.
- `site/` - static build-log site.
- `wolfram/` - generated Wolfram model package.

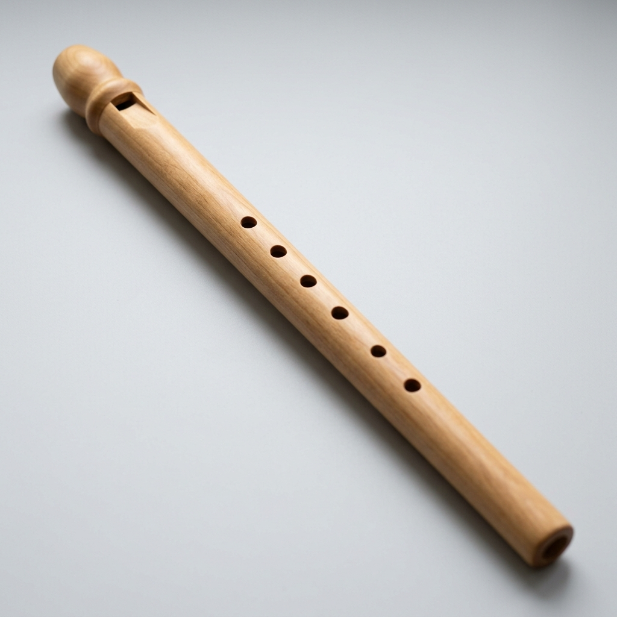
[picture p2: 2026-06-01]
images/hero-render.png

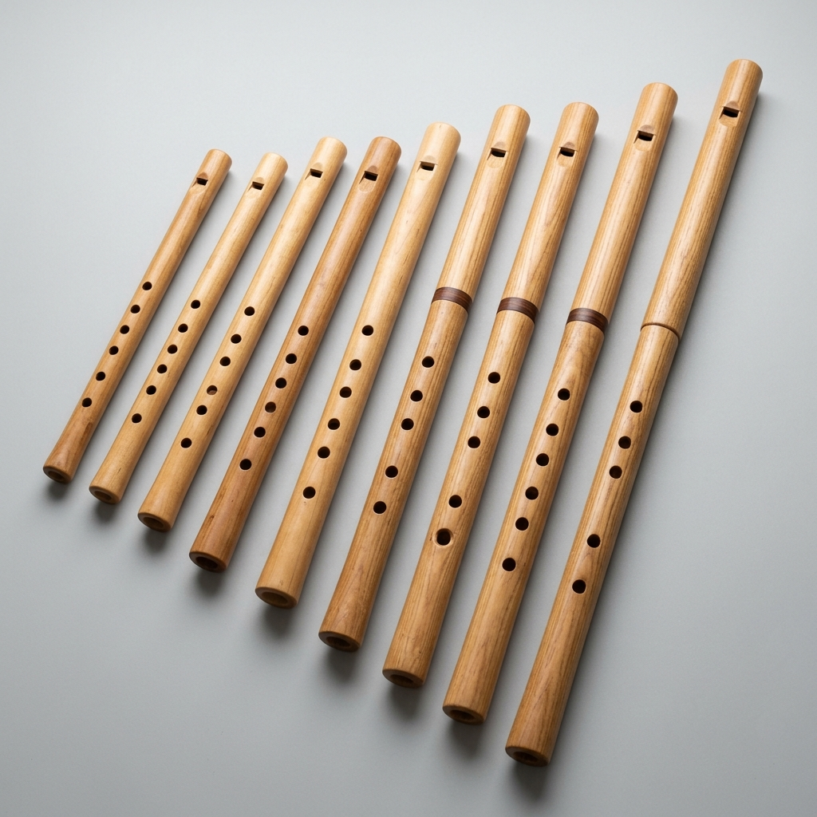
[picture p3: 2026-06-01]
images/family-group.png

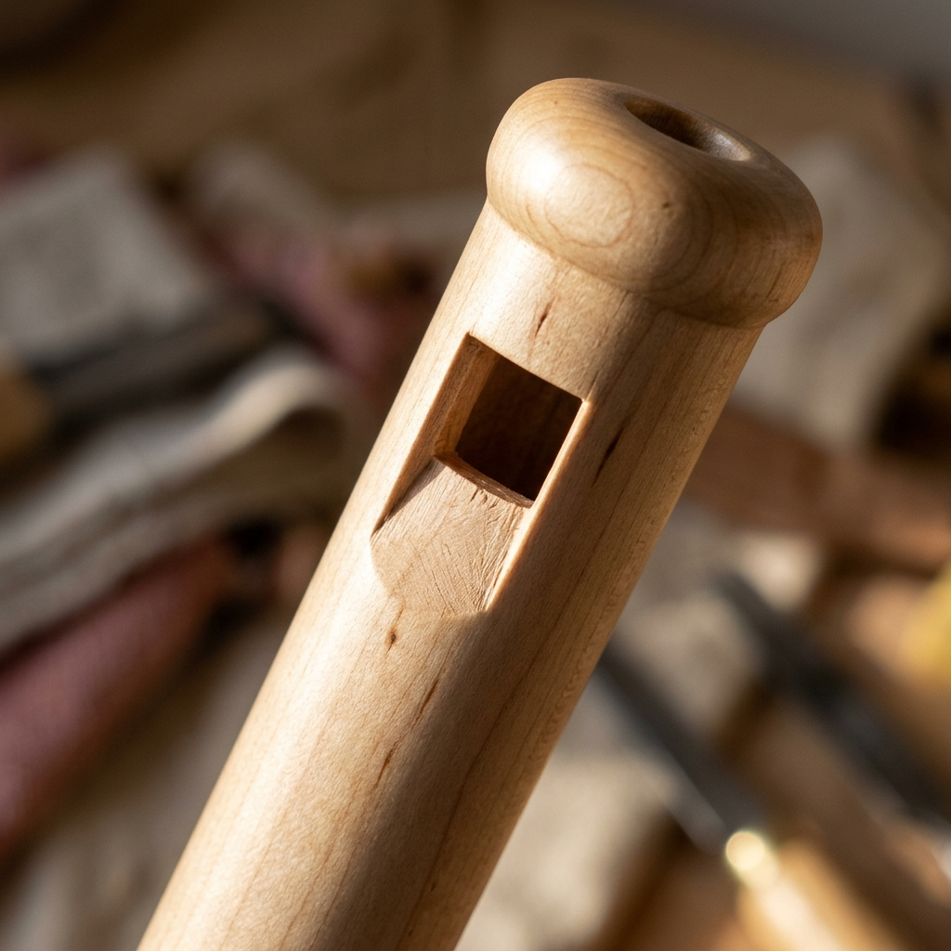
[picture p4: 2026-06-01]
images/macro/fipple-sound-window.png

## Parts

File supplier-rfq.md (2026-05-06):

# Supplier RFQ Draft

Subject: Quote request for straight-grain woodwind blanks and optional ferrule stock

Hello,

I am building a small run of long fipple flutes and need stable straight-grain blanks suitable for bored woodwind bodies.

Please quote the following:

- 4 to 8 blanks, 1.25 to 1.50 in square or round, 30 to 38 in long.
- Species options: elder, locust, ash, maple, cherry, walnut, or similar stable hardwood.
- Moisture content and straightness/grain-runout information.
- Any longer stock suitable for 85-90 cm flute bodies.
- Optional thin-wall brass tube or hardwood ferrule stock around 1.25 to 1.40 in ID/OD range.

The blanks will be drilled or split-routed along the long axis, then turned and tuned, so straight grain and low checking risk matter more than figure.

Please include unit price, volume price, lead time, shipping estimate, and any recommended substitutes.

Thank you,
Tony Koop

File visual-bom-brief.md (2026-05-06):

# Visual BOM Brief

Create one image-forward BOM plate with:

- hero view of a kaval, an Alghosazi, and the fipple-head section;
- item rows for body blank, fipple plug, cork/ferrule, drilling template, finish, and validation tools;
- callouts that distinguish make vs buy parts;
- source status labels: verified price, spec only, or shop stock.

Image sources:

- Use real shop photos after P0/P1 prototypes exist.
- Until then, use `images/hero.png` and the SVG drawings as concept placeholders.
- Do not use vendor or Fujara Flutes photos directly in the BOM without permission.

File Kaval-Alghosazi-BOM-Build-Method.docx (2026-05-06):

# Kaval + Alghosazi Fipple Flutes Capstone Print Packet

Generated: 2026-05-05 Packet folder: /mnt/c/Users/Tony/Documents/GitHub/kaval-alghosazi-flutes

## File Map

File | Purpose
design.md | Project intent, catalog metadata, assumptions, and validation plan.
bom.csv | Starter bill of materials with part categories, quantities, drawing refs, and notes.
sourcing.csv | Supplier/search tracker with specs, price/date fields, lead time, substitutes, and risks.
cut-list.csv | Rough/final stock sizes, material, grain/orientation, operations, yield, and offcuts.
drawing-brief.md | Manufacturing drawing and technical product sketch brief.
assembly-manual.md | Shop-facing sequence, tools, fixtures, safety, tuning, finishing, and maintenance notes.
validation.csv | Target/measured values, tolerance, environment, result, and tuning/build action log.
supplier-rfq.md | Supplier email/request-for-quote starter.
visual-bom-brief.md | Art direction for an image-forward visual BOM.
wolfram-starter.wl | Wolfram starter for physics, optimization, visualization, and validation.
README.md | Project artifact.
alghosazi-hole-schedule.csv | Project artifact.
double-drone-spec.csv | Project artifact.
family-spec.csv | Project artifact.
hole-schedule.csv | Project artifact.
kaval-hole-schedule.csv | Project artifact.
photo-shotlist.md | Project artifact.
risks.md | Project artifact.
sources.md | Project artifact.

## design.md

Project intent, catalog metadata, assumptions, and validation plan.

# Kaval + Alghosazi Fipple Flutes

Packet ID: KAV-ALG-FAM-001
Family: open-pipe woodwind / duct-fipple flute
Pipeline: cnc-lathe hybrid: split blank or deep bore, fipple head, lathe rounding, optional two-piece joint
Date: 2026-05-06
Done-bar references: fujara, flutes, drone-flutes, pistalka, transverse-flute

## Project Intent

Design a buildable family of long fipple kavals and Alghosazi flutes that feel close to the Fujara Flutes references while using Tony’s existing fujara/flute workshop logic: parametric dimensions, a controllable fipple sound-window head, split-blank CNC or deep-bore construction, validation tables, and documented tuning loops.

The first physical goal is not a perfect production run. It is a controlled prototype ladder: prove the fipple head, build one A3 5-hole kaval, build one A#3 Alghosazi with a thumb hole, then decide whether the two-piece and double-drone versions deserve full CAD.

## Source And Scope

External reference pages checked:

- Fujara Flutes Kaval page: 5-hole fipple kavals, 7-hole expanded kavals, lengths from about 62-90 cm, and double Kaval/Kavalghoza drone concept.
- Fujara Flutes Alghosazi page: fipple adaptation of Anasazi-style flute, top hole moved to the back as a thumb hole, lengths from about 70-85 cm, and a double-drone option.
- Flutopedia Anasazi tuning notes: used only to justify the Alghosazi starter offset set as an Anasazi-derived primary sequence.

Local source artifacts inspected:

- fujara/design-table/fujara_equations.md and SolidWorks dimension extracts for fipple/flue plug geometry.
- drone-flutes/design.md and flutes/skills/parametric-design-table.md for open-pipe, shop, and validation workflow.
- pistalka/docs/build-packet/design.md for a compact fipple-flute build sequence.

## Governing Model

These flutes are modeled as open-open cylindrical fipple flutes with a non-NAF fujara-style sound-window end correction.

f = c / (2 * L_eff)
c = 13552 in/s at about 68 F
L_eff = physical_labium_to_foot + foot_end_correction + sound_window_correction
foot_end_correction ~= 0.6 * bore_radius
sound_window_correction = measured prototype value, not Tony's NAF K2 table

For first-pass hole placement, the packet uses a proportional open-pipe layout:

x_from_labium = labium_to_foot * 2^(-semitone_offset / 12)
x_from_foot = labium_to_foot - x_from_labium

The hole schedule is intentionally a starter drill schedule. The builder drills undersized, tunes the root by trimming the foot, then opens each hole upward by careful reaming/undercutting. If a hole goes sharp, the recovery is wax test, bushing, or a rebuilt body.

family-spec.csv includes estimated_sound_window_correction_in. Positive values mean the fipple/window system or added acoustic path must make the instrument behave longer than the visible labium-to-foot length. Negative values mean the source-observed body length is overlong for the nominal root under a simple open-pipe model; treat those as overlength blanks to trim or as evidence that the commercial key naming may not equal the all-closed root.

## Scale Plans

### 5-Hole Fipple Kaval

The 5-hole kaval follows the published C-reference pitch set:

0, +2, +3, +6, +7, +8 semitones
Example in C: C D D# F# G G#

### 7-Hole Fipple Kaval

The expanded kaval adds the two half-step options described by the reference page:

0, +2, +3, +4, +6, +7, +8, +9 semitones
Example in C: C D D# E F# G G# A

### Alghosazi

The Alghosazi starter scale uses an Anasazi-derived primary sequence. The top hole is placed on the back as a thumb hole, matching the design note from the reference page.

0, +2, +4, +7, +9, +11, +12 semitones
Example in A#: A# C D F G A A#

This is marked as a musical-design assumption. If Tony wants a different Alghosazi mode after listening to examples, change the offsets in Kaval-Alghosazi-Design.xlsx and regenerate hole-schedule.csv.

## Fujara-Style Fipple Head

The requested head architecture is:

mouth at end -> rectangular inlet -> internal windway/flue -> side true sound window -> splitting edge -> main bore

Starter dimensions:

Feature | Kaval Starter | Alghosazi Starter | Notes
Top end to true window datum | 1.45-1.65 in | 1.65-1.80 in | Adjust for comfort and joint location.
Windway height | 0.033-0.045 in | 0.035-0.048 in | Start with removable flue plug trials.
Windway width | 0.45-0.55 in | 0.45-0.58 in | About 55-65 percent of bore.
Window length | 0.25-0.38 in | 0.28-0.42 in | Widen/lengthen only after tone test.
Splitting edge offset KPI | 0.005-0.015 in | 0.005-0.015 in | Borrowed from Tony’s fujara canary, not a final law.
Plug fit | wax-sealed slip | wax-sealed slip | Removable until final voicing.

## Two-Piece And Double Options

The two-piece option is a shop convenience and tuning risk, not a decorative afterthought. Use it only after a solid prototype speaks well.

- Tenon engagement: 1.25 in minimum.
- Cork compression: fit by sanding; no forced assembly.
- Joint location: avoid placing the joint within 0.75 in of a tone hole.
- Bore step: less than 0.005 in at the joint after final sanding.
- Ferrule: recommended for A/A# bodies and double-flute assemblies.

Double-drone versions are documented in double-drone-spec.csv and drawings/double-drone-layout.svg. Each side gets its own windway so the melody flute can be played alone and the drone can be tuned independently.

## Family Table

See family-spec.csv for the source of truth. The core starter members are:

Member | Role
KAV-A3-5H | First kaval prototype.
KAV-AS3-7H | Two-piece expanded kaval prototype.
ALG-AS3-J2 | First Alghosazi prototype.
ALG-A3-J3 | Three-piece Alghosazi joint stress test.

## Manufacturing Path

Preferred path for the first two prototypes:

1. Make a removable fipple-head test tile from scrap.
2. Build a split-blank body so the bore, windway, and window are visible and correctable.
3. Glue and turn only after the fipple speaks.
4. Drill holes undersized from a laser/CNC template or V-block setup.
5. Tune root first, then holes from foot upward.
6. Record measurements in validation.csv and update the next prototype.

Deep-bore drilling is allowed for later solid-body builds. Use the skill reference headstock-driven-deep-bore-drilling.md before attempting a long solid blank.

## Assumptions

- A4 = 440 Hz.
- 68 F speed-of-sound baseline.
- Website lengths are used as precedent dimensions, not guaranteed acoustic formulas.
- Alghosazi tuning is a starter interpretation based on contemporary Anasazi-tuned six-hole practice.
- Tone hole positions ignore final hole-diameter perturbation until measured prototype data exists.
- The fipple head is Tony’s derived design and must be validated by physical tests.

## bom.csv

Starter bill of materials with part categories, quantities, drawing refs, and notes.

item | assembly | part | qty | spec | make_buy | est_cost_usd | source_status | drawing_ref | notes
BOM-001 | all | Primary body blank | 1 per flute | Straight-grain elder, locust, ash, maple, cherry, or walnut; length per family-spec plus 2 in trim | buy | 25-90 | spec only | drawings/*-body.svg | Avoid runout through tone holes and joint tenons.
BOM-002 | head | Removable fipple/flue plug | 1 plus 2 test plugs | Hard maple, pear, or dense straight-grain scrap; 0.033-0.045 in windway height trials | make | 5 | shop scrap ok | drawings/fipple-head-section.svg | Wax-sealed removable plug makes voicing iteration survivable.
BOM-003 | joint | Cork sheet or natural cork rings | 1 strip per joint | 1/32 to 1/16 in cork, sanded to airtight slip fit | buy | 8-15 | verify before purchase | drawings/two-piece-joint.svg | Use only on removable joints; permanent split bodies use glue.
BOM-004 | joint | Brass or hardwood ferrule sleeve | optional | Thin brass tube or hardwood collar sized to body OD | buy/make | 10-25 | verify diameter | drawings/two-piece-joint.svg | Recommended for long A/A# bodies and double-flute assemblies.
BOM-005 | finish | Exterior finish | 1 | Shellac, polymerized oil, or oil/wax; keep windway and bore lightly sealed only after tuning | buy | 10-30 | shop stock likely | assembly-manual.md | No heavy finish on splitting edge.
BOM-006 | fixture | V-block and drilling template stock | 1 set | MDF/plywood V-block, laser-cut paper/acrylic hole templates, 1/4 in dowel pins | make | 10-20 | shop stock likely | cnc/setup-sheet.md | Template holes should be undersized pilots.
BOM-007 | validation | Tuning/measurement kit | 1 | Chromatic tuner, thermometer/hygrometer, calipers, small round files, recording device | use shop kit | 0-60 | existing kit likely | validation.csv | Record temperature with every tuning pass.

## sourcing.csv

Supplier/search tracker with specs, price/date fields, lead time, substitutes, and risks.

component | required_spec | search_terms | candidate_supplier | price_each | date_checked | lead_time | substitutes | risk
straight-grain hardwood blanks | 1.25-1.50 in square or round, 28-38 in long, stable and dry | elder wood blank, locust spindle blank, ash turning blank, maple turning blank | local hardwood dealer / Woodcraft / Rockler / Global Wood Source | TBD | TBD | TBD | maple/cherry/walnut for prototype | Species and grain affect cracking and tone; verify straight grain before purchase.
cork joint material | thin sheet or rings, sandable, airtight | woodwind tenon cork sheet 1/32 1/16 | music repair supplier / Amazon / McMaster | TBD | TBD | TBD | waxed hemp thread for tests | Loose joint leaks; tight joint cracks socket.
brass ferrule sleeve | ID/OD matched to selected body, thin wall | brass tube 1.25 inch 1.375 inch thin wall | K&S, McMaster, OnlineMetals | TBD | TBD | TBD | hardwood collar turned on lathe | Metal sleeve changes exterior feel and may buzz if poorly fitted.
small brad point drill bits and reamers | 1/8 to 3/8 in, sharp, clean entry | brad point drill bit set small reamer | Woodcraft / Rockler / McMaster | TBD | TBD | TBD | number drill bits plus tapered reamer | Tearout around holes shifts tuning and looks sloppy.

## cut-list.csv

Rough/final stock sizes, material, grain/orientation, operations, yield, and offcuts.

member_id | blank_part | material | qty | rough_size_in | final_size_in | grain_orientation | operation | yield_notes
KAV-GS3-5H | main body blank | Locust or elder | 1 | 1.625 x 1.625 x 33.102 | OD 1.375, bore 0.875, length 31.102 | straight along bore axis | square, split or bore, route/drill, glue if split, turn/round, tune foot | Leave 2 in trim for root tuning and chuck/fixture allowance.
KAV-GS3-5H | joint tenon/socket allowance | Locust or elder plus cork/ferrule | 1 | extra 2.5 in distributed around joint | 1.250 in tenon engagement, 0.003-0.006 in cork-adjusted compression | same as body | turn tenon/socket after bore alignment is proven | Cut joint after body is acoustically proven on a sacrificial overlength blank.
KAV-A3-5H | main body blank | Elder | 1 | 1.625 x 1.625 x 31.134 | OD 1.375, bore 0.875, length 29.134 | straight along bore axis | square, split or bore, route/drill, glue if split, turn/round, tune foot | Leave 2 in trim for root tuning and chuck/fixture allowance.
KAV-A3-5H | joint tenon/socket allowance | Elder plus cork/ferrule | 1 | extra 2.5 in distributed around joint | 1.250 in tenon engagement, 0.003-0.006 in cork-adjusted compression | same as body | turn tenon/socket after bore alignment is proven | Cut joint after body is acoustically proven on a sacrificial overlength blank.
KAV-B3-5H | main body blank | Elder | 1 | 1.562 x 1.562 x 28.378 | OD 1.312, bore 0.812, length 26.378 | straight along bore axis | square, split or bore, route/drill, glue if split, turn/round, tune foot | Leave 2 in trim for root tuning and chuck/fixture allowance.
KAV-C4-5H | main body blank | Elder, maple, or cherry | 1 | 1.500 x 1.500 x 26.409 | OD 1.250, bore 0.750, length 24.409 | straight along bore axis | square, split or bore, route/drill, glue if split, turn/round, tune foot | Leave 2 in trim for root tuning and chuck/fixture allowance.
KAV-A3-7H | main body blank | Elder | 1 | 1.650 x 1.650 x 37.433 | OD 1.400, bore 0.875, length 35.433 | straight along bore axis | square, split or bore, route/drill, glue if split, turn/round, tune foot | Leave 2 in trim for root tuning and chuck/fixture allowance.
KAV-AS3-7H | main body blank | Dogwood or elder | 1 | 1.650 x 1.650 x 35.465 | OD 1.400, bore 0.875, length 33.465 | straight along bore axis | square, split or bore, route/drill, glue if split, turn/round, tune foot | Leave 2 in trim for root tuning and chuck/fixture allowance.
KAV-AS3-7H | joint tenon/socket allowance | Dogwood or elder plus cork/ferrule | 1 | extra 2.5 in distributed around joint | 1.250 in tenon engagement, 0.003-0.006 in cork-adjusted compression | same as body | turn tenon/socket after bore alignment is proven | Cut joint after body is acoustically proven on a sacrificial overlength blank.
KAV-B3-7H | main body blank | Elder | 1 | 1.562 x 1.562 x 29.165 | OD 1.312, bore 0.812, length 27.165 | straight along bore axis | square, split or bore, route/drill, glue if split, turn/round, tune foot | Leave 2 in trim for root tuning and chuck/fixture allowance.
ALG-AS3-J2 | main body blank | Ash | 1 | 1.625 x 1.625 x 34.283 | OD 1.375, bore 0.875, length 32.283 | straight along bore axis | square, split or bore, route/drill, glue if split, turn/round, tune foot | Leave 2 in trim for root tuning and chuck/fixture allowance.
ALG-AS3-J2 | joint tenon/socket allowance | Ash plus cork/ferrule | 1 | extra 2.5 in distributed around joint | 1.250 in tenon engagement, 0.003-0.006 in cork-adjusted compression | same as body | turn tenon/socket after bore alignment is proven | Cut joint after body is acoustically proven on a sacrificial overlength blank.
ALG-AS3-SOLID | main body blank | Locust | 1 | 1.625 x 1.625 x 35.465 | OD 1.375, bore 0.875, length 33.465 | straight along bore axis | square, split or bore, route/drill, glue if split, turn/round, tune foot | Leave 2 in trim for root tuning and chuck/fixture allowance.
ALG-A3-J3 | main body blank | Oak | 1 | 1.625 x 1.625 x 30.740 | OD 1.375, bore 0.875, length 28.740 | straight along bore axis | square, split or bore, route/drill, glue if split, turn/round, tune foot | Leave 2 in trim for root tuning and chuck/fixture allowance.
ALG-A3-J3 | joint tenon/socket allowance | Oak plus cork/ferrule | 1 | extra 2.5 in distributed around joint | 1.250 in tenon engagement, 0.003-0.006 in cork-adjusted compression | same as body | turn tenon/socket after bore alignment is proven | Cut joint after body is acoustically proven on a sacrificial overlength blank.
ALG-B3-SOLID | main body blank | Elder or maple | 1 | 1.562 x 1.562 x 29.559 | OD 1.312, bore 0.812, length 27.559 | straight along bore axis | square, split or bore, route/drill, glue if split, turn/round, tune foot | Leave 2 in trim for root tuning and chuck/fixture allowance.

## drawing-brief.md

Manufacturing drawing and technical product sketch brief.

# Drawing Brief

## Required Views

- Family overview: each member as a scaled open-pipe body with bore ID and total length.
- Hole layout: kaval and Alghosazi separate, measured from labium and from foot.
- Fipple head section: end mouth inlet, windway, flue plug, true sound window, splitting edge, bore.
- Two-piece joint section: tenon, socket, cork wrap, ferrule/collar, bore continuity.
- Double-drone layout: two bores, independent windways, melody side, drone side, thumb vent.

## Datums

- Datum A: labium/splitting-edge plane.
- Datum B: tuned foot end.
- Datum C: bore centerline.
- Datum D: back thumb-hole centerline for Alghosazi.

## Tolerances

- Bore ID: +/-0.005 in after reaming/lapping.
- Hole center: +/-0.020 in before tuning; final pitch matters more than nominal center.
- Windway height: +/-0.002 in once a plug speaks.
- Joint bore step: less than 0.005 in.
- Noncritical exterior: +/-0.030 in.

## Drawing Outputs

Generated SVGs live in drawings/. Build-critical dimensions come from Kaval-Alghosazi-Design.xlsx, family-spec.csv, and hole-schedule.csv, not from raster images.

## assembly-manual.md

Shop-facing sequence, tools, fixtures, safety, tuning, finishing, and maintenance notes.

# Assembly Manual

## Safety And Setup

- Wear eye and lung protection when drilling, routing, sanding, or turning.
- Do not route a long round blank without a stable V-block or split-blank fixture.
- Keep the splitting edge protected until final voicing.
- Mark the labium datum, foot datum, bore centerline, and back thumb-hole line before any irreversible cut.

## Prototype Ladder

### P0: Fipple Head Tile

1. Cut a 4 in scrap block with the selected bore diameter or a half-bore test channel.
2. Cut the end mouth inlet.
3. Fit a removable flue plug with 0.033, 0.038, and 0.045 in shim trials.
4. Cut a side true sound window and splitting edge.
5. Blow through the end inlet and record which plug/window combination speaks cleanly.
6. Do not build a full flute until this tile produces stable tone.

### P1: First Kaval Body

1. Select KAV-A3-5H.
2. Mill the blank overlength by at least 2 in.
3. Split the blank, route the bore halves and registration pin holes, or deep-bore the solid blank after proving setup on scrap.
4. Create the fipple head and removable plug.
5. Prove the root tone with no finger holes.
6. Trim the foot to bring the all-closed root toward A3.
7. Transfer hole positions from kaval-hole-schedule.csv.
8. Drill each hole undersized.
9. Tune holes from the foot upward by reaming slowly.
10. Record every before/after pitch in validation.csv.

### P1: First Alghosazi Body

1. Select ALG-AS3-J2.
2. Build as a solid body first if joint risk feels high; otherwise cut the two-piece joint after the bore is proven.
3. Mark the rear thumb-hole line before drilling.
4. Drill the thumb hole undersized and validate reach with the actual player grip.
5. Tune the primary sequence and record whether the scale feels musically right.

### P2: Jointed Version

1. Cut the body overlength and prove tone before final jointing.
2. Locate the joint away from holes and away from the fipple head.
3. Turn tenon and socket with a 1.25 in engagement target.
4. Add cork or waxed thread until the joint seals without force.
5. Check bore step with a dowel, light, and feeler test.
6. Re-test root and all holes after the joint is fitted.

### P3: Double Drone

1. Build melody and drone tubes separately.
2. Tune the melody side alone.
3. Tune the drone side alone, including rear thumb vent if used.
4. Join the bodies temporarily with clamps or bands before permanent collars.
5. Test pressure sharing with both windways.
6. Only then commit to a permanent double-body fixture or decorative binding.

## Finishing

- Finish exterior after tuning.
- Keep heavy oil, shellac, and wax out of the windway and splitting edge.
- Seal bore lightly only after final measurements.
- Recheck pitch after finish cure.

## Maintenance

- Let the bore dry after playing.
- Remove the fipple plug only if the design uses a wax-sealed removable plug.
- Do not store jointed bodies assembled under high humidity swings.
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

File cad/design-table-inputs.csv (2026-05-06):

member_id | target_note | total_length_in | bore_id_in | body_od_in | top_to_window_in | hole_count | construction
KAV-GS3-5H | G#3 | 31.102 | 0.8750 | 1.3750 | 1.600 | 5 | solid or split blank; optional two-piece joint
KAV-A3-5H | A3 | 29.134 | 0.8750 | 1.3750 | 1.600 | 5 | two-piece optional hand-cut joint
KAV-B3-5H | B3 | 26.378 | 0.8125 | 1.3125 | 1.500 | 5 | solid split blank
KAV-C4-5H | C4 | 24.409 | 0.7500 | 1.2500 | 1.450 | 5 | solid split blank
KAV-A3-7H | A3 | 35.433 | 0.8750 | 1.4000 | 1.650 | 7 | solid split blank
KAV-AS3-7H | A#3 | 33.465 | 0.8750 | 1.4000 | 1.650 | 7 | two-piece optional hand-cut joint
KAV-B3-7H | B3 | 27.165 | 0.8125 | 1.3125 | 1.500 | 7 | solid split blank
ALG-AS3-J2 | A#3 | 32.283 | 0.8750 | 1.3750 | 1.800 | 6 | two-piece hand-cut joint
ALG-AS3-SOLID | A#3 | 33.465 | 0.8750 | 1.3750 | 1.800 | 6 | solid split blank
ALG-A3-J3 | A3 | 28.740 | 0.8750 | 1.3750 | 1.750 | 6 | three-piece hand-cut joint
ALG-B3-SOLID | B3 | 27.559 | 0.8125 | 1.3125 | 1.650 | 6 | solid split blank

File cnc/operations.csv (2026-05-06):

op_id | name | machine | tool | workholding | datum | inputs | outputs | checks | notes
OP-010 | Review design package and mark datums | Bench | Calipers, square, marking knife, center punch | Flat bench, drawing packet | Primary centerline / face A | design.md; drawing-brief.md; cut-list.csv | shop-marked blank; datum checklist | All stock dimensions exceed finished dimensions plus allowance; Units match drawings
OP-110 | Prepare bore blank | Table saw / jointer / planer | Rip blade, jointer knives, planer | Push blocks, featherboard | Face A and centerline | cut-list.csv | square bore blank | Blank straightness checked; Grain direction marked
OP-210 | Create bore | Lathe or CNC router | Long brad-point bit, reamer, or ball/end mill for split blank | Tailstock vise/carrier or flip jig with datum pins | Centerline A-B | drawing-brief.md; family-spec.csv | bored or routed body half | Bore wander checked on scrap; Bore diameter measured at both ends | Use the deep-bore technique reference when the bore is long and straight.
OP-310 | Cut tone features | CNC router / drill press / laser template | 1/8 in upcut spiral, brad-point bits, or printed drill guide | V-block, centerline fence, registration pins | Embouchure end datum | scale table; drawing-brief.md | tone holes / windows | Hole spacing matches scale table; Undercut/tuning allowance left
OP-900 | Validation and tuning pass | Bench | Chromatic tuner, calipers, scale, recording device | Padded bench | Same acoustic datum used in design.md | validation.csv; finished part | updated validation.csv; process photo | Measured frequency recorded; Cents error computed; Tuning trim notes written

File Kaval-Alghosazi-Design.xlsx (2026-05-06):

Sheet: Master_Inputs
name | value | units | notes
speed_of_sound | 13552 | in/s | 68 F baseline
A4_reference | 440 | Hz | concert pitch
windway_height_min | 0.033 | in | fipple plug trial
windway_height_nom | 0.038 | in | starter
windway_height_max | 0.045 | in | fipple plug trial
splitting_edge_offset_min | 0.005 | in | target KPI
splitting_edge_offset_nom | 0.009 | in | Tony fujara-style canary
splitting_edge_offset_max | 0.015 | in | target KPI
joint_tenon_length | 1.25 | in | minimum engagement

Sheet: Family_Spec
member_id | instrument | key | midi | target_hz_formula | target_hz_cached | total_length_in | bore_id_in | body_od_in | labium_to_foot_in | open_pipe_leff_formula | sound_window_corr_formula | hole_offsets_st | source_basis
KAV-GS3-5H | Fipple Kaval | G#3 | 56 | 207.652 | 207.652 | 31.102 | 0.875 | 1.375 | 29.502 | 32.631 | 3.129 | 2 3 6 7 8 | Fujara Flutes observed G# kaval length 79 cm
KAV-A3-5H | Fipple Kaval | A3 | 57 | 220 | 220 | 29.134 | 0.875 | 1.375 | 27.534 | 30.8 | 3.266 | 2 3 6 7 8 | Fujara Flutes observed A kaval length 74 cm
KAV-B3-5H | Fipple Kaval | B3 | 59 | 246.942 | 246.942 | 26.378 | 0.8125 | 1.3125 | 24.878 | 27.44 | 2.562 | 2 3 6 7 8 | Fujara Flutes observed B kaval length 67 cm
KAV-C4-5H | Fipple Kaval | C4 | 60 | 261.626 | 261.626 | 24.409 | 0.75 | 1.25 | 22.959 | 25.9 | 2.94 | 2 3 6 7 8 | Fujara Flutes observed C kaval length 62 cm
KAV-A3-7H | Fipple Kaval | A3 | 57 | 220 | 220 | 35.433 | 0.875 | 1.4 | 33.783 | 30.8 | -2.983 | 2 3 4 6 7 8 9 | Fujara Flutes observed 7-hole A kaval length 90 cm
KAV-AS3-7H | Fipple Kaval | A#3 | 58 | 233.082 | 233.082 | 33.465 | 0.875 | 1.4 | 31.815 | 29.071 | -2.743 | 2 3 4 6 7 8 9 | Fujara Flutes observed 7-hole A# kaval length 85 cm
KAV-B3-7H | Fipple Kaval | B3 | 59 | 246.942 | 246.942 | 27.165 | 0.8125 | 1.3125 | 25.665 | 27.44 | 1.774 | 2 3 4 6 7 8 9 | Fujara Flutes observed 7-hole B kaval length 69 cm
ALG-AS3-J2 | Fipple Alghosazi | A#3 | 58 | 233.082 | 233.082 | 32.283 | 0.875 | 1.375 | 30.483 | 29.071 | -1.412 | 2 4 7 9 11 12 | Fujara Flutes observed A# Alghosazi length 82 cm
ALG-AS3-SOLID | Fipple Alghosazi | A#3 | 58 | 233.082 | 233.082 | 33.465 | 0.875 | 1.375 | 31.665 | 29.071 | -2.593 | 2 4 7 9 11 12 | Fujara Flutes observed solid A# Alghosazi length 85 cm
ALG-A3-J3 | Fipple Alghosazi | A3 | 57 | 220 | 220 | 28.74 | 0.875 | 1.375 | 26.99 | 30.8 | 3.81 | 2 4 7 9 11 12 | Fujara Flutes observed A Alghosazi length 73 cm
ALG-B3-SOLID | Fipple Alghosazi | B3 | 59 | 246.942 | 246.942 | 27.559 | 0.8125 | 1.3125 | 25.909 | 27.44 | 1.531 | 2 4 7 9 11 12 | Fujara Flutes observed B Alghosazi length 70 cm

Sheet: Hole_Schedules
member_id | hole_no_from_foot | offset_st | target_hz | x_from_labium_in | x_from_foot_in | starter_drill_in | target_final_dia_in | orientation | formula
KAV-GS3-5H | 1 | 2 | 233.082 | 26.284 | 3.219 | 0.1875 | 0.2500 | front | x_from_labium = labium_to_foot * 2^(-offset_st/12); tune upward by enlarging
KAV-GS3-5H | 2 | 3 | 246.942 | 24.808 | 4.694 | 0.1875 | 0.2500 | front | x_from_labium = labium_to_foot * 2^(-offset_st/12); tune upward by enlarging
KAV-GS3-5H | 3 | 6 | 293.665 | 20.861 | 8.641 | 0.2188 | 0.3000 | front | x_from_labium = labium_to_foot * 2^(-offset_st/12); tune upward by enlarging
KAV-GS3-5H | 4 | 7 | 311.127 | 19.69 | 9.812 | 0.2188 | 0.3000 | front | x_from_labium = labium_to_foot * 2^(-offset_st/12); tune upward by enlarging
KAV-GS3-5H | 5 | 8 | 329.628 | 18.585 | 10.917 | 0.2188 | 0.3000 | front | x_from_labium = labium_to_foot * 2^(-offset_st/12); tune upward by enlarging
KAV-A3-5H | 1 | 2 | 246.942 | 24.53 | 3.004 | 0.1875 | 0.2500 | front | x_from_labium = labium_to_foot * 2^(-offset_st/12); tune upward by enlarging
KAV-A3-5H | 2 | 3 | 261.626 | 23.153 | 4.381 | 0.1875 | 0.2500 | front | x_from_labium = labium_to_foot * 2^(-offset_st/12); tune upward by enlarging
KAV-A3-5H | 3 | 6 | 311.127 | 19.469 | 8.064 | 0.2188 | 0.3000 | front | x_from_labium = labium_to_foot * 2^(-offset_st/12); tune upward by enlarging
KAV-A3-5H | 4 | 7 | 329.628 | 18.377 | 9.157 | 0.2188 | 0.3000 | front | x_from_labium = labium_to_foot * 2^(-offset_st/12); tune upward by enlarging
KAV-A3-5H | 5 | 8 | 349.228 | 17.345 | 10.189 | 0.2188 | 0.3000 | front | x_from_labium = labium_to_foot * 2^(-offset_st/12); tune upward by enlarging
KAV-B3-5H | 1 | 2 | 277.183 | 22.164 | 2.714 | 0.1875 | 0.2500 | front | x_from_labium = labium_to_foot * 2^(-offset_st/12); tune upward by enlarging
KAV-B3-5H | 2 | 3 | 293.665 | 20.92 | 3.958 | 0.1875 | 0.2500 | front | x_from_labium = labium_to_foot * 2^(-offset_st/12); tune upward by enlarging
KAV-B3-5H | 3 | 6 | 349.228 | 17.591 | 7.287 | 0.2188 | 0.3000 | front | x_from_labium = labium_to_foot * 2^(-offset_st/12); tune upward by enlarging
KAV-B3-5H | 4 | 7 | 369.994 | 16.604 | 8.274 | 0.2188 | 0.3000 | front | x_from_labium = labium_to_foot * 2^(-offset_st/12); tune upward by enlarging
KAV-B3-5H | 5 | 8 | 391.995 | 15.672 | 9.206 | 0.2188 | 0.3000 | front | x_from_labium = labium_to_foot * 2^(-offset_st/12); tune upward by enlarging
KAV-C4-5H | 1 | 2 | 293.665 | 20.455 | 2.505 | 0.1875 | 0.2500 | front | x_from_labium = labium_to_foot * 2^(-offset_st/12); tune upward by enlarging
KAV-C4-5H | 2 | 3 | 311.127 | 19.307 | 3.653 | 0.1875 | 0.2500 | front | x_from_labium = labium_to_foot * 2^(-offset_st/12); tune upward by enlarging
KAV-C4-5H | 3 | 6 | 369.994 | 16.235 | 6.725 | 0.2188 | 0.3000 | front | x_from_labium = labium_to_foot * 2^(-offset_st/12); tune upward by enlarging
KAV-C4-5H | 4 | 7 | 391.995 | 15.324 | 7.636 | 0.2188 | 0.3000 | front | x_from_labium = labium_to_foot * 2^(-offset_st/12); tune upward by enlarging
KAV-C4-5H | 5 | 8 | 415.305 | 14.464 | 8.496 | 0.2188 | 0.3000 | front | x_from_labium = labium_to_foot * 2^(-offset_st/12); tune upward by enlarging
KAV-A3-7H | 1 | 2 | 246.942 | 30.097 | 3.686 | 0.1875 | 0.2500 | front | x_from_labium = labium_to_foot * 2^(-offset_st/12); tune upward by enlarging
KAV-A3-7H | 2 | 3 | 261.626 | 28.408 | 5.375 | 0.1875 | 0.2500 | front | x_from_labium = labium_to_foot * 2^(-offset_st/12); tune upward by enlarging
KAV-A3-7H | 3 | 4 | 277.183 | 26.814 | 6.969 | 0.2188 | 0.3000 | front | x_from_labium = labium_to_foot * 2^(-offset_st/12); tune upward by enlarging
KAV-A3-7H | 4 | 6 | 311.127 | 23.888 | 9.895 | 0.2188 | 0.3000 | front | x_from_labium = labium_to_foot * 2^(-offset_st/12); tune upward by enlarging
KAV-A3-7H | 5 | 7 | 329.628 | 22.547 | 11.236 | 0.2188 | 0.3000 | front | x_from_labium = labium_to_foot * 2^(-offset_st/12); tune upward by enlarging
KAV-A3-7H | 6 | 8 | 349.228 | 21.282 | 12.501 | 0.2188 | 0.3000 | front | x_from_labium = labium_to_foot * 2^(-offset_st/12); tune upward by enlarging
KAV-A3-7H | 7 | 9 | 369.994 | 20.088 | 13.696 | 0.2188 | 0.3000 | front | x_from_labium = labium_to_foot * 2^(-offset_st/12); tune upward by enlarging
KAV-AS3-7H | 1 | 2 | 261.626 | 28.344 | 3.471 | 0.1875 | 0.2500 | front | x_from_labium = labium_to_foot * 2^(-offset_st/12); tune upward by enlarging
KAV-AS3-7H | 2 | 3 | 277.183 | 26.753 | 5.062 | 0.1875 | 0.2500 | front | x_from_labium = labium_to_foot * 2^(-offset_st/12); tune upward by enlarging
KAV-AS3-7H | 3 | 4 | 293.665 | 25.251 | 6.563 | 0.2188 | 0.3000 | front | x_from_labium = labium_to_foot * 2^(-offset_st/12); tune upward by enlarging
KAV-AS3-7H | 4 | 6 | 329.628 | 22.496 | 9.318 | 0.2188 | 0.3000 | front | x_from_labium = labium_to_foot * 2^(-offset_st/12); tune upward by enlarging
KAV-AS3-7H | 5 | 7 | 349.228 | 21.234 | 10.581 | 0.2188 | 0.3000 | front | x_from_labium = labium_to_foot * 2^(-offset_st/12); tune upward by enlarging
KAV-AS3-7H | 6 | 8 | 369.994 | 20.042 | 11.773 | 0.2188 | 0.3000 | front | x_from_labium = labium_to_foot * 2^(-offset_st/12); tune upward by enlarging
KAV-AS3-7H | 7 | 9 | 391.995 | 18.917 | 12.898 | 0.2188 | 0.3000 | front | x_from_labium = labium_to_foot * 2^(-offset_st/12); tune upward by enlarging
KAV-B3-7H | 1 | 2 | 277.183 | 22.865 | 2.8 | 0.1875 | 0.2500 | front | x_from_labium = labium_to_foot * 2^(-offset_st/12); tune upward by enlarging
KAV-B3-7H | 2 | 3 | 293.665 | 21.582 | 4.083 | 0.1875 | 0.2500 | front | x_from_labium = labium_to_foot * 2^(-offset_st/12); tune upward by enlarging
KAV-B3-7H | 3 | 4 | 311.127 | 20.371 | 5.295 | 0.2188 | 0.3000 | front | x_from_labium = labium_to_foot * 2^(-offset_st/12); tune upward by enlarging
KAV-B3-7H | 4 | 6 | 349.228 | 18.148 | 7.517 | 0.2188 | 0.3000 | front | x_from_labium = labium_to_foot * 2^(-offset_st/12); tune upward by enlarging
KAV-B3-7H | 5 | 7 | 369.994 | 17.13 | 8.536 | 0.2188 | 0.3000 | front | x_from_labium = labium_to_foot * 2^(-offset_st/12); tune upward by enlarging
KAV-B3-7H | 6 | 8 | 391.995 | 16.168 | 9.497 | 0.2188 | 0.3000 | front | x_from_labium = labium_to_foot * 2^(-offset_st/12); tune upward by enlarging
KAV-B3-7H | 7 | 9 | 415.305 | 15.261 | 10.405 | 0.2188 | 0.3000 | front | x_from_labium = labium_to_foot * 2^(-offset_st/12); tune upward by enlarging
ALG-AS3-J2 | 1 | 2 | 261.626 | 27.158 | 3.326 | 0.1875 | 0.2500 | front | x_from_labium = labium_to_foot * 2^(-offset_st/12); tune upward by enlarging
ALG-AS3-J2 | 2 | 4 | 293.665 | 24.195 | 6.289 | 0.1875 | 0.2500 | front | x_from_labium = labium_to_foot * 2^(-offset_st/12); tune upward by enlarging
ALG-AS3-J2 | 3 | 7 | 349.228 | 20.345 | 10.138 | 0.1875 | 0.2500 | front | x_from_labium = labium_to_foot * 2^(-offset_st/12); tune upward by enlarging
ALG-AS3-J2 | 4 | 9 | 391.995 | 18.126 | 12.358 | 0.2188 | 0.3125 | front | x_from_labium = labium_to_foot * 2^(-offset_st/12); tune upward by enlarging
ALG-AS3-J2 | 5 | 11 | 440 | 16.148 | 14.335 | 0.2188 | 0.3125 | front | x_from_labium = labium_to_foot * 2^(-offset_st/12); tune upward by enlarging
ALG-AS3-J2 | 6 | 12 | 466.164 | 15.242 | 15.242 | 0.2188 | 0.3125 | back thumb | x_from_labium = labium_to_foot * 2^(-offset_st/12); tune upward by enlarging
ALG-AS3-SOLID | 1 | 2 | 261.626 | 28.21 | 3.455 | 0.1875 | 0.2500 | front | x_from_labium = labium_to_foot * 2^(-offset_st/12); tune upward by enlarging
ALG-AS3-SOLID | 2 | 4 | 293.665 | 25.132 | 6.532 | 0.1875 | 0.2500 | front | x_from_labium = labium_to_foot * 2^(-offset_st/12); tune upward by enlarging
ALG-AS3-SOLID | 3 | 7 | 349.228 | 21.134 | 10.531 | 0.1875 | 0.2500 | front | x_from_labium = labium_to_foot * 2^(-offset_st/12); tune upward by enlarging
ALG-AS3-SOLID | 4 | 9 | 391.995 | 18.828 | 12.837 | 0.2188 | 0.3125 | front | x_from_labium = labium_to_foot * 2^(-offset_st/12); tune upward by enlarging
ALG-AS3-SOLID | 5 | 11 | 440 | 16.774 | 14.891 | 0.2188 | 0.3125 | front | x_from_labium = labium_to_foot * 2^(-offset_st/12); tune upward by enlarging
ALG-AS3-SOLID | 6 | 12 | 466.164 | 15.832 | 15.832 | 0.2188 | 0.3125 | back thumb | x_from_labium = labium_to_foot * 2^(-offset_st/12); tune upward by enlarging
ALG-A3-J3 | 1 | 2 | 246.942 | 24.045 | 2.945 | 0.1875 | 0.2500 | front | x_from_labium = labium_to_foot * 2^(-offset_st/12); tune upward by enlarging
ALG-A3-J3 | 2 | 4 | 277.183 | 21.422 | 5.568 | 0.1875 | 0.2500 | front | x_from_labium = labium_to_foot * 2^(-offset_st/12); tune upward by enlarging
ALG-A3-J3 | 3 | 7 | 329.628 | 18.014 | 8.976 | 0.1875 | 0.2500 | front | x_from_labium = labium_to_foot * 2^(-offset_st/12); tune upward by enlarging
ALG-A3-J3 | 4 | 9 | 369.994 | 16.048 | 10.942 | 0.2188 | 0.3125 | front | x_from_labium = labium_to_foot * 2^(-offset_st/12); tune upward by enlarging
ALG-A3-J3 | 5 | 11 | 415.305 | 14.298 | 12.693 | 0.2188 | 0.3125 | front | x_from_labium = labium_to_foot * 2^(-offset_st/12); tune upward by enlarging
ALG-A3-J3 | 6 | 12 | 440 | 13.495 | 13.495 | 0.2188 | 0.3125 | back thumb | x_from_labium = labium_to_foot * 2^(-offset_st/12); tune upward by enlarging
ALG-B3-SOLID | 1 | 2 | 277.183 | 23.082 | 2.827 | 0.1875 | 0.2500 | front | x_from_labium = labium_to_foot * 2^(-offset_st/12); tune upward by enlarging
ALG-B3-SOLID | 2 | 4 | 311.127 | 20.564 | 5.345 | 0.1875 | 0.2500 | front | x_from_labium = labium_to_foot * 2^(-offset_st/12); tune upward by enlarging
ALG-B3-SOLID | 3 | 7 | 369.994 | 17.292 | 8.617 | 0.1875 | 0.2500 | front | x_from_labium = labium_to_foot * 2^(-offset_st/12); tune upward by enlarging
ALG-B3-SOLID | 4 | 9 | 415.305 | 15.406 | 10.503 | 0.2188 | 0.3125 | front | x_from_labium = labium_to_foot * 2^(-offset_st/12); tune upward by enlarging
ALG-B3-SOLID | 5 | 11 | 466.164 | 13.725 | 12.184 | 0.2188 | 0.3125 | front | x_from_labium = labium_to_foot * 2^(-offset_st/12); tune upward by enlarging
ALG-B3-SOLID | 6 | 12 | 493.883 | 12.955 | 12.955 | 0.2188 | 0.3125 | back thumb | x_from_labium = labium_to_foot * 2^(-offset_st/12); tune upward by enlarging

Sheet: Fipple_Head
feature | starter_value_in | range_or_formula | notes
top_to_window | 1.6 | see family-spec | end mouth inlet to true sound window datum
windway_height | 0.038 | 0.033-0.045 | use removable plugs
windway_width | 0.5 | 0.55-0.65*bore_id | adjust after P0
window_length | 0.32 | 0.25-0.42 | length along body
window_width | 0.5 | 0.55-0.65*bore_id | start narrow
splitting_edge_offset | 0.009 | 0.005-0.015 | driven KPI

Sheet: Validation_Template
field | formula_or_note
cents_error | =1200*LOG(measured_hz/target_hz,2)
root tuning | trim foot to raise; rebuild or sleeve if sharp
hole tuning | enlarge to raise; wax/bush if sharp

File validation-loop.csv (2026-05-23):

check_id | packet_artifact | readiness_before | prediction_source | target | tolerance | method | measured_result | status | next_action | evidence
vl001 | docs/p0-fipple-head-measurement.md | L1_packet | fujara-style head starter dimensions | P0 head tile speaks cleanly with recorded windway/window setup | measurement_required | Build scrap P0 tile; test three plug shims; record audio/tuner and physical settings. | TBD | measurement_required | Do not commit full-body hole schedule until one speaking head setup is logged. | future tuner capture, photo set, and shop log
vl002 | sound-window-correction-log.csv | L1_packet | open-open model plus source-observed body lengths | Back-solved sound-window correction for KAV-A3-5H or matched P0 body | measurement_required | Measure unholed root, compute L_eff=c/(2f), subtract labium-to-foot and foot end correction. | TBD | measurement_required | Update workbook, family-spec, and hole schedules only after this row has measured data. | future sound-window-correction-log.csv measured row

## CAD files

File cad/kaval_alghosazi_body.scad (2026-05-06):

// Kaval + Alghosazi fipple flute starter, units = inches.
$fn = 96;

member = "KAV-A3-5H";
total_length = 29.134;
bore_id = 0.875;
body_od = 1.375;
top_to_window = 1.60;
windway_h = 0.038;
windway_w = 0.500;
window_l = 0.320;
window_w = 0.500;

module body_blank() {
  difference() {
    cylinder(h = total_length, d = body_od);
    translate([0,0,-0.02]) cylinder(h = total_length + 0.04, d = bore_id);
  }
}

module true_sound_window() {
  translate([-window_w/2, body_od/2 - 0.02, total_length - top_to_window])
    cube([window_w, 0.12, window_l], center=false);
}

module end_mouth_inlet() {
  translate([-windway_w/2, body_od/2 - 0.08, total_length - 0.32])
    cube([windway_w, 0.18, 0.28], center=false);
}

module flute_body_preview() {
  difference() {
    body_blank();
    true_sound_window();
    end_mouth_inlet();
  }
}

flute_body_preview();

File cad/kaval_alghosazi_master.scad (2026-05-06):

// =============================================================
// Kaval_Alghosazi — OpenSCAD Master-Shape Starter
// =============================================================
// Generated 2026-05-05 by generate_openscad_starter.py.
// Units: inches.
//
// This is a master-shape STARTER — captures bore profile + tone-hole
// positions to first order.  Voicing/embouchure/labium geometry must
// be refined by hand because it's tuning-sensitive.
//
// Governing model: Open pipe (or stopped pipe; see design.md)
//     f_n = n·v / (2·L_eff)            (open-open)
//     f_n = (2n-1)·v / (4·L_eff)       (open-stopped)
// with L_eff = L + end-correction(s) and Tony's NAF K2 bore correction
// applied where the bore diameter falls in the K2 lookup range.
// =============================================================

$fn = 96;

// --------- INPUT PARAMETERS (edit these) ---------------------

c_in_per_sec   = 13510;     // speed of sound (in/s @ ~68F)
bore_dia       = 0.005;       // bore inside diameter
total_length   = 5;      // overall length
wall_in        = 0.20;        // wall thickness

// Tone holes: [position_from_top_in, diameter_in, note_label]
holes = [
    // Edit for actual fingering chart from design.md
    [total_length*0.55, 0.30, "low"],
    [total_length*0.65, 0.31, "+1"],
    [total_length*0.74, 0.30, "+2"],
    [total_length*0.83, 0.32, "+3"],
    [total_length*0.92, 0.30, "+4"],
];

module open_pipe_body() {
    difference() {
        cylinder(h=total_length, d=bore_dia + 2*wall_in);
        translate([0, 0, -0.01])
            cylinder(h=total_length+0.02, d=bore_dia);
        for (h = holes) {
            translate([bore_dia/2 + wall_in, 0, h[0]])
                rotate([0, 90, 0])
                    cylinder(h=wall_in*3, d=h[1], center=true);
        }
    }
}

open_pipe_body();
echo(str("Bore: ", bore_dia, " in;  Length: ", total_length, " in;  Holes: ", len(holes)));

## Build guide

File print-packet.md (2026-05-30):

# Kaval + Alghosazi Fipple Flutes Capstone Print Packet

Generated: 2026-05-05
Packet folder: `/mnt/c/Users/Tony/Documents/GitHub/kaval-alghosazi-flutes`

## File Map

| File | Purpose |
| --- | --- |
| `design.md` | Project intent, catalog metadata, assumptions, and validation plan. |
| `bom.csv` | Starter bill of materials with part categories, quantities, drawing refs, and notes. |
| `sourcing.csv` | Supplier/search tracker with specs, price/date fields, lead time, substitutes, and risks. |
| `cut-list.csv` | Rough/final stock sizes, material, grain/orientation, operations, yield, and offcuts. |
| `drawing-brief.md` | Manufacturing drawing and technical product sketch brief. |
| `assembly-manual.md` | Shop-facing sequence, tools, fixtures, safety, tuning, finishing, and maintenance notes. |
| `validation.csv` | Target/measured values, tolerance, environment, result, and tuning/build action log. |
| `supplier-rfq.md` | Supplier email/request-for-quote starter. |
| `visual-bom-brief.md` | Art direction for an image-forward visual BOM. |
| `wolfram-starter.wl` | Wolfram starter for physics, optimization, visualization, and validation. |
| `README.md` | Project artifact. |
| `alghosazi-hole-schedule.csv` | Project artifact. |
| `double-drone-spec.csv` | Project artifact. |
| `family-spec.csv` | Project artifact. |
| `hole-schedule.csv` | Project artifact. |
| `kaval-hole-schedule.csv` | Project artifact. |
| `photo-shotlist.md` | Project artifact. |
| `risks.md` | Project artifact. |
| `sources.md` | Project artifact. |

## design.md

Project intent, catalog metadata, assumptions, and validation plan.

# Kaval + Alghosazi Fipple Flutes

**Packet ID:** KAV-ALG-FAM-001  
**Family:** open-pipe woodwind / duct-fipple flute  
**Pipeline:** cnc-lathe hybrid: split blank or deep bore, fipple head, lathe rounding, optional two-piece joint  
**Date:** 2026-05-06  
**Done-bar references:** `fujara`, `flutes`, `drone-flutes`, `pistalka`, `transverse-flute`

## Project Intent

Design a buildable family of long fipple kavals and Alghosazi flutes that feel close to the Fujara Flutes references while using Tony's existing fujara/flute workshop logic: parametric dimensions, a controllable fipple sound-window head, split-blank CNC or deep-bore construction, validation tables, and documented tuning loops.

The first physical goal is not a perfect production run. It is a controlled prototype ladder: prove the fipple head, build one A3 5-hole kaval, build one A#3 Alghosazi with a thumb hole, then decide whether the two-piece and double-drone versions deserve full CAD.

## Source And Scope

External reference pages checked:

- Fujara Flutes Kaval page: 5-hole fipple kavals, 7-hole expanded kavals, lengths from about 62-90 cm, and double Kaval/Kavalghoza drone concept.
- Fujara Flutes Alghosazi page: fipple adaptation of Anasazi-style flute, top hole moved to the back as a thumb hole, lengths from about 70-85 cm, and a double-drone option.
- Flutopedia Anasazi tuning notes: used only to justify the Alghosazi starter offset set as an Anasazi-derived primary sequence.

Local source artifacts inspected:

- `fujara/design-table/fujara_equations.md` and SolidWorks dimension extracts for fipple/flue plug geometry.
- `drone-flutes/design.md` and `flutes/skills/parametric-design-table.md` for open-pipe, shop, and validation workflow.
- `pistalka/docs/build-packet/design.md` for a compact fipple-flute build sequence.

## Governing Model

These flutes are modeled as **open-open cylindrical fipple flutes** with a non-NAF fujara-style sound-window end correction.

```text
f = c / (2 * L_eff)
c = 13552 in/s at about 68 F
L_eff = physical_labium_to_foot + foot_end_correction + sound_window_correction
foot_end_correction ~= 0.6 * bore_radius
sound_window_correction = measured prototype value, not Tony's NAF K2 table
```

For first-pass hole placement, the packet uses a proportional open-pipe layout:

```text
x_from_labium = labium_to_foot * 2^(-semitone_offset / 12)
x_from_foot = labium_to_foot - x_from_labium
```

The hole schedule is intentionally a **starter drill schedule**. The builder drills undersized, tunes the root by trimming the foot, then opens each hole upward by careful reaming/undercutting. If a hole goes sharp, the recovery is wax test, bushing, or a rebuilt body.

`family-spec.csv` includes `estimated_sound_window_correction_in`. Positive values mean the fipple/window system or added acoustic path must make the instrument behave longer than the visible labium-to-foot length. Negative values mean the source-observed body length is overlong for the nominal root under a simple open-pipe model; treat those as overlength blanks to trim or as evidence that the commercial key naming may not equal the all-closed root.

## Scale Plans

### 5-Hole Fipple Kaval

The 5-hole kaval follows the published C-reference pitch set:

```text
0, +2, +3, +6, +7, +8 semitones
Example in C: C D D# F# G G#
```

### 7-Hole Fipple Kaval

The expanded kaval adds the two half-step options described by the reference page:

```text
0, +2, +3, +4, +6, +7, +8, +9 semitones
Example in C: C D D# E F# G G# A
```

### Alghosazi

The Alghosazi starter scale uses an Anasazi-derived primary sequence. The top hole is placed on the back as a thumb hole, matching the design note from the reference page.

```text
0, +2, +4, +7, +9, +11, +12 semitones
Example in A#: A# C D F G A A#
```

This is marked as a musical-design assumption. If Tony wants a different Alghosazi mode after listening to examples, change the offsets in `Kaval-Alghosazi-Design.xlsx` and regenerate `hole-schedule.csv`.

## Fujara-Style Fipple Head

The requested head architecture is:

```text
mouth at end -> rectangular inlet -> internal windway/flue -> side true sound window -> splitting edge -> main bore
```

Starter dimensions:

| Feature | Kaval Starter | Alghosazi Starter | Notes |
| --- | ---: | ---: | --- |
| Top end to true window datum | 1.45-1.65 in | 1.65-1.80 in | Adjust for comfort and joint location. |
| Windway height | 0.033-0.045 in | 0.035-0.048 in | Start with removable flue plug trials. |
| Windway width | 0.45-0.55 in | 0.45-0.58 in | About 55-65 percent of bore. |
| Window length | 0.25-0.38 in | 0.28-0.42 in | Widen/lengthen only after tone test. |
| Splitting edge offset KPI | 0.005-0.015 in | 0.005-0.015 in | Borrowed from Tony's fujara canary, not a final law. |
| Plug fit | wax-sealed slip | wax-sealed slip | Removable until final voicing. |

## Two-Piece And Double Options

The two-piece option is a **shop convenience and tuning risk**, not a decorative afterthought. Use it only after a solid prototype speaks well.

- Tenon engagement: 1.25 in minimum.
- Cork compression: fit by sanding; no forced assembly.
- Joint location: avoid placing the joint within 0.75 in of a tone hole.
- Bore step: less than 0.005 in at the joint after final sanding.
- Ferrule: recommended for A/A# bodies and double-flute assemblies.

Double-drone versions are documented in `double-drone-spec.csv` and `drawings/double-drone-layout.svg`. Each side gets its own windway so the melody flute can be played alone and the drone can be tuned independently.

## Family Table

See `family-spec.csv` for the source of truth. The core starter members are:

| Member | Role |
| --- | --- |
| `KAV-A3-5H` | First kaval prototype. |
| `KAV-AS3-7H` | Two-piece expanded kaval prototype. |
| `ALG-AS3-J2` | First Alghosazi prototype. |
| `ALG-A3-J3` | Three-piece Alghosazi joint stress test. |

## Manufacturing Path

Preferred path for the first two prototypes:

1. Make a removable fipple-head test tile from scrap.
2. Build a split-blank body so the bore, windway, and window are visible and correctable.
3. Glue and turn only after the fipple speaks.
4. Drill holes undersized from a laser/CNC template or V-block setup.
5. Tune root first, then holes from foot upward.
6. Record measurements in `validation.csv` and update the next prototype.

Deep-bore drilling is allowed for later solid-body builds. Use the skill reference `headstock-driven-deep-bore-drilling.md` before attempting a long solid blank.

## Assumptions

- A4 = 440 Hz.
- 68 F speed-of-sound baseline.
- Website lengths are used as precedent dimensions, not guaranteed acoustic formulas.
- Alghosazi tuning is a starter interpretation based on contemporary Anasazi-tuned six-hole practice.
- Tone hole positions ignore final hole-diameter perturbation until measured prototype data exists.
- The fipple head is Tony's derived design and must be validated by physical tests.

## bom.csv

Starter bill of materials with part categories, quantities, drawing refs, and notes.

| item | assembly | part | qty | spec | make_buy | est_cost_usd | source_status | drawing_ref | notes |
| --- | --- | --- | --- | --- | --- | --- | --- | --- | --- |
| BOM-001 | all | Primary body blank | 1 per flute | Straight-grain elder, locust, ash, maple, cherry, or walnut; length per family-spec plus 2 in trim | buy | 25-90 | spec only | drawings/*-body.svg | Avoid runout through tone holes and joint tenons. |
| BOM-002 | head | Removable fipple/flue plug | 1 plus 2 test plugs | Hard maple, pear, or dense straight-grain scrap; 0.033-0.045 in windway height trials | make | 5 | shop scrap ok | drawings/fipple-head-section.svg | Wax-sealed removable plug makes voicing iteration survivable. |
| BOM-003 | joint | Cork sheet or natural cork rings | 1 strip per joint | 1/32 to 1/16 in cork, sanded to airtight slip fit | buy | 8-15 | verify before purchase | drawings/two-piece-joint.svg | Use only on removable joints; permanent split bodies use glue. |
| BOM-004 | joint | Brass or hardwood ferrule sleeve | optional | Thin brass tube or hardwood collar sized to body OD | buy/make | 10-25 | verify diameter | drawings/two-piece-joint.svg | Recommended for long A/A# bodies and double-flute assemblies. |
| BOM-005 | finish | Exterior finish | 1 | Shellac, polymerized oil, or oil/wax; keep windway and bore lightly sealed only after tuning | buy | 10-30 | shop stock likely | assembly-manual.md | No heavy finish on splitting edge. |
| BOM-006 | fixture | V-block and drilling template stock | 1 set | MDF/plywood V-block, laser-cut paper/acrylic hole templates, 1/4 in dowel pins | make | 10-20 | shop stock likely | cnc/setup-sheet.md | Template holes should be undersized pilots. |
| BOM-007 | validation | Tuning/measurement kit | 1 | Chromatic tuner, thermometer/hygrometer, calipers, small round files, recording device | use shop kit | 0-60 | existing kit likely | validation.csv | Record temperature with every tuning pass. |

## sourcing.csv

Supplier/search tracker with specs, price/date fields, lead time, substitutes, and risks.

| component | required_spec | search_terms | candidate_supplier | price_each | date_checked | lead_time | substitutes | risk |
| --- | --- | --- | --- | --- | --- | --- | --- | --- |
| straight-grain hardwood blanks | 1.25-1.50 in square or round, 28-38 in long, stable and dry | elder wood blank, locust spindle blank, ash turning blank, maple turning blank | local hardwood dealer / Woodcraft / Rockler / Global Wood Source | TBD | TBD | TBD | maple/cherry/walnut for prototype | Species and grain affect cracking and tone; verify straight grain before purchase. |
| cork joint material | thin sheet or rings, sandable, airtight | woodwind tenon cork sheet 1/32 1/16 | music repair supplier / Amazon / McMaster | TBD | TBD | TBD | waxed hemp thread for tests | Loose joint leaks; tight joint cracks socket. |
| brass ferrule sleeve | ID/OD matched to selected body, thin wall | brass tube 1.25 inch 1.375 inch thin wall | K&S, McMaster, OnlineMetals | TBD | TBD | TBD | hardwood collar turned on lathe | Metal sleeve changes exterior feel and may buzz if poorly fitted. |
| small brad point drill bits and reamers | 1/8 to 3/8 in, sharp, clean entry | brad point drill bit set small reamer | Woodcraft / Rockler / McMaster | TBD | TBD | TBD | number drill bits plus tapered reamer | Tearout around holes shifts tuning and looks sloppy. |

## cut-list.csv

Rough/final stock sizes, material, grain/orientation, operations, yield, and offcuts.

| member_id | blank_part | material | qty | rough_size_in | final_size_in | grain_orientation | operation | yield_notes |
| --- | --- | --- | --- | --- | --- | --- | --- | --- |
| KAV-GS3-5H | main body blank | Locust or elder | 1 | 1.625 x 1.625 x 33.102 | OD 1.375, bore 0.875, length 31.102 | straight along bore axis | square, split or bore, route/drill, glue if split, turn/round, tune foot | Leave 2 in trim for root tuning and chuck/fixture allowance. |
| KAV-GS3-5H | joint tenon/socket allowance | Locust or elder plus cork/ferrule | 1 | extra 2.5 in distributed around joint | 1.250 in tenon engagement, 0.003-0.006 in cork-adjusted compression | same as body | turn tenon/socket after bore alignment is proven | Cut joint after body is acoustically proven on a sacrificial overlength blank. |
| KAV-A3-5H | main body blank | Elder | 1 | 1.625 x 1.625 x 31.134 | OD 1.375, bore 0.875, length 29.134 | straight along bore axis | square, split or bore, route/drill, glue if split, turn/round, tune foot | Leave 2 in trim for root tuning and chuck/fixture allowance. |
| KAV-A3-5H | joint tenon/socket allowance | Elder plus cork/ferrule | 1 | extra 2.5 in distributed around joint | 1.250 in tenon engagement, 0.003-0.006 in cork-adjusted compression | same as body | turn tenon/socket after bore alignment is proven | Cut joint after body is acoustically proven on a sacrificial overlength blank. |
| KAV-B3-5H | main body blank | Elder | 1 | 1.562 x 1.562 x 28.378 | OD 1.312, bore 0.812, length 26.378 | straight along bore axis | square, split or bore, route/drill, glue if split, turn/round, tune foot | Leave 2 in trim for root tuning and chuck/fixture allowance. |
| KAV-C4-5H | main body blank | Elder, maple, or cherry | 1 | 1.500 x 1.500 x 26.409 | OD 1.250, bore 0.750, length 24.409 | straight along bore axis | square, split or bore, route/drill, glue if split, turn/round, tune foot | Leave 2 in trim for root tuning and chuck/fixture allowance. |
| KAV-A3-7H | main body blank | Elder | 1 | 1.650 x 1.650 x 37.433 | OD 1.400, bore 0.875, length 35.433 | straight along bore axis | square, split or bore, route/drill, glue if split, turn/round, tune foot | Leave 2 in trim for root tuning and chuck/fixture allowance. |
| KAV-AS3-7H | main body blank | Dogwood or elder | 1 | 1.650 x 1.650 x 35.465 | OD 1.400, bore 0.875, length 33.465 | straight along bore axis | square, split or bore, route/drill, glue if split, turn/round, tune foot | Leave 2 in trim for root tuning and chuck/fixture allowance. |
| KAV-AS3-7H | joint tenon/socket allowance | Dogwood or elder plus cork/ferrule | 1 | extra 2.5 in distributed around joint | 1.250 in tenon engagement, 0.003-0.006 in cork-adjusted compression | same as body | turn tenon/socket after bore alignment is proven | Cut joint after body is acoustically proven on a sacrificial overlength blank. |
| KAV-B3-7H | main body blank | Elder | 1 | 1.562 x 1.562 x 29.165 | OD 1.312, bore 0.812, length 27.165 | straight along bore axis | square, split or bore, route/drill, glue if split, turn/round, tune foot | Leave 2 in trim for root tuning and chuck/fixture allowance. |
| ALG-AS3-J2 | main body blank | Ash | 1 | 1.625 x 1.625 x 34.283 | OD 1.375, bore 0.875, length 32.283 | straight along bore axis | square, split or bore, route/drill, glue if split, turn/round, tune foot | Leave 2 in trim for root tuning and chuck/fixture allowance. |
| ALG-AS3-J2 | joint tenon/socket allowance | Ash plus cork/ferrule | 1 | extra 2.5 in distributed around joint | 1.250 in tenon engagement, 0.003-0.006 in cork-adjusted compression | same as body | turn tenon/socket after bore alignment is proven | Cut joint after body is acoustically proven on a sacrificial overlength blank. |
| ALG-AS3-SOLID | main body blank | Locust | 1 | 1.625 x 1.625 x 35.465 | OD 1.375, bore 0.875, length 33.465 | straight along bore axis | square, split or bore, route/drill, glue if split, turn/round, tune foot | Leave 2 in trim for root tuning and chuck/fixture allowance. |
| ALG-A3-J3 | main body blank | Oak | 1 | 1.625 x 1.625 x 30.740 | OD 1.375, bore 0.875, length 28.740 | straight along bore axis | square, split or bore, route/drill, glue if split, turn/round, tune foot | Leave 2 in trim for root tuning and chuck/fixture allowance. |
| ALG-A3-J3 | joint tenon/socket allowance | Oak plus cork/ferrule | 1 | extra 2.5 in distributed around joint | 1.250 in tenon engagement, 0.003-0.006 in cork-adjusted compression | same as body | turn tenon/socket after bore alignment is proven | Cut joint after body is acoustically proven on a sacrificial overlength blank. |
| ALG-B3-SOLID | main body blank | Elder or maple | 1 | 1.562 x 1.562 x 29.559 | OD 1.312, bore 0.812, length 27.559 | straight along bore axis | square, split or bore, route/drill, glue if split, turn/round, tune foot | Leave 2 in trim for root tuning and chuck/fixture allowance. |

## drawing-brief.md

Manufacturing drawing and technical product sketch brief.

# Drawing Brief

## Required Views

- Family overview: each member as a scaled open-pipe body with bore ID and total length.
- Hole layout: kaval and Alghosazi separate, measured from labium and from foot.
- Fipple head section: end mouth inlet, windway, flue plug, true sound window, splitting edge, bore.
- Two-piece joint section: tenon, socket, cork wrap, ferrule/collar, bore continuity.
- Double-drone layout: two bores, independent windways, melody side, drone side, thumb vent.

## Datums

- Datum A: labium/splitting-edge plane.
- Datum B: tuned foot end.
- Datum C: bore centerline.
- Datum D: back thumb-hole centerline for Alghosazi.

## Tolerances

- Bore ID: +/-0.005 in after reaming/lapping.
- Hole center: +/-0.020 in before tuning; final pitch matters more than nominal center.
- Windway height: +/-0.002 in once a plug speaks.
- Joint bore step: less than 0.005 in.
- Noncritical exterior: +/-0.030 in.

## Drawing Outputs

Generated SVGs live in `drawings/`. Build-critical dimensions come from `Kaval-Alghosazi-Design.xlsx`, `family-spec.csv`, and `hole-schedule.csv`, not from raster images.

## assembly-manual.md

Shop-facing sequence, tools, fixtures, safety, tuning, finishing, and maintenance notes.

# Assembly Manual

## Safety And Setup

- Wear eye and lung protection when drilling, routing, sanding, or turning.
- Do not route a long round blank without a stable V-block or split-blank fixture.
- Keep the splitting edge protected until final voicing.
- Mark the labium datum, foot datum, bore centerline, and back thumb-hole line before any irreversible cut.

## Prototype Ladder

### P0: Fipple Head Tile

1. Cut a 4 in scrap block with the selected bore diameter or a half-bore test channel.
2. Cut the end mouth inlet.
3. Fit a removable flue plug with 0.033, 0.038, and 0.045 in shim trials.
4. Cut a side true sound window and splitting edge.
5. Blow through the end inlet and record which plug/window combination speaks cleanly.
6. Do not build a full flute until this tile produces stable tone.

### P1: First Kaval Body

1. Select `KAV-A3-5H`.
2. Mill the blank overlength by at least 2 in.
3. Split the blank, route the bore halves and registration pin holes, or deep-bore the solid blank after proving setup on scrap.
4. Create the fipple head and removable plug.
5. Prove the root tone with no finger holes.
6. Trim the foot to bring the all-closed root toward A3.
7. Transfer hole positions from `kaval-hole-schedule.csv`.
8. Drill each hole undersized.
9. Tune holes from the foot upward by reaming slowly.
10. Record every before/after pitch in `validation.csv`.

### P1: First Alghosazi Body

1. Select `ALG-AS3-J2`.
2. Build as a solid body first if joint risk feels high; otherwise cut the two-piece joint after the bore is proven.
3. Mark the rear thumb-hole line before drilling.
4. Drill the thumb hole undersized and validate reach with the actual player grip.
5. Tune the primary sequence and record whether the scale feels musically right.

### P2: Jointed Version

1. Cut the body overlength and prove tone before final jointing.
2. Locate the joint away from holes and away from the fipple head.
3. Turn tenon and socket with a 1.25 in engagement target.
4. Add cork or waxed thread until the joint seals without force.
5. Check bore step with a dowel, light, and feeler test.
6. Re-test root and all holes after the joint is fitted.

### P3: Double Drone

1. Build melody and drone tubes separately.
2. Tune the melody side alone.
3. Tune the drone side alone, including rear thumb vent if used.
4. Join the bodies temporarily with clamps or bands before permanent collars.
5. Test pressure sharing with both windways.
6. Only then commit to a permanent double-body fixture or decorative binding.

## Finishing

- Finish exterior after tuning.
- Keep heavy oil, shellac, and wax out of the windway and splitting edge.
- Seal bore lightly only after final measurements.
- Recheck pitch after finish cure.

## Maintenance

- Let the bore dry after playing.
- Remove the fipple plug only if the design uses a wax-sealed removable plug.
- Do not store jointed bodies assembled under high humidity swings.

## validation.csv

Target/measured values, tolerance, environment, result, and tuning/build action log.

| member_id | test_id | target | target_value | measured_value | tolerance | environment | pass_fail | action |
| --- | --- | --- | --- | --- | --- | --- | --- | --- |
| KAV-GS3-5H | VAL-ROOT | root G#3 | 207.652 Hz |  | +/-25 cents P1, +/-10 cents P2 | TBD temp/RH |  | Trim foot shorter to raise pitch; rebuild/extend foot if sharp. |
| KAV-GS3-5H | VAL-H1 | hole 1 offset +2 st | 233.082 Hz |  | +/-25 cents P1, +/-10 cents P2 | TBD temp/RH |  | Enlarge/undercut slowly to raise; wax or bushing recovery if sharp. |
| KAV-GS3-5H | VAL-H2 | hole 2 offset +3 st | 246.942 Hz |  | +/-25 cents P1, +/-10 cents P2 | TBD temp/RH |  | Enlarge/undercut slowly to raise; wax or bushing recovery if sharp. |
| KAV-GS3-5H | VAL-H3 | hole 3 offset +6 st | 293.665 Hz |  | +/-25 cents P1, +/-10 cents P2 | TBD temp/RH |  | Enlarge/undercut slowly to raise; wax or bushing recovery if sharp. |
| KAV-GS3-5H | VAL-H4 | hole 4 offset +7 st | 311.127 Hz |  | +/-25 cents P1, +/-10 cents P2 | TBD temp/RH |  | Enlarge/undercut slowly to raise; wax or bushing recovery if sharp. |
| KAV-GS3-5H | VAL-H5 | hole 5 offset +8 st | 329.628 Hz |  | +/-25 cents P1, +/-10 cents P2 | TBD temp/RH |  | Enlarge/undercut slowly to raise; wax or bushing recovery if sharp. |
| KAV-A3-5H | VAL-ROOT | root A3 | 220.000 Hz |  | +/-25 cents P1, +/-10 cents P2 | TBD temp/RH |  | Trim foot shorter to raise pitch; rebuild/extend foot if sharp. |
| KAV-A3-5H | VAL-H1 | hole 1 offset +2 st | 246.942 Hz |  | +/-25 cents P1, +/-10 cents P2 | TBD temp/RH |  | Enlarge/undercut slowly to raise; wax or bushing recovery if sharp. |
| KAV-A3-5H | VAL-H2 | hole 2 offset +3 st | 261.626 Hz |  | +/-25 cents P1, +/-10 cents P2 | TBD temp/RH |  | Enlarge/undercut slowly to raise; wax or bushing recovery if sharp. |
| KAV-A3-5H | VAL-H3 | hole 3 offset +6 st | 311.127 Hz |  | +/-25 cents P1, +/-10 cents P2 | TBD temp/RH |  | Enlarge/undercut slowly to raise; wax or bushing recovery if sharp. |
| KAV-A3-5H | VAL-H4 | hole 4 offset +7 st | 329.628 Hz |  | +/-25 cents P1, +/-10 cents P2 | TBD temp/RH |  | Enlarge/undercut slowly to raise; wax or bushing recovery if sharp. |
| KAV-A3-5H | VAL-H5 | hole 5 offset +8 st | 349.228 Hz |  | +/-25 cents P1, +/-10 cents P2 | TBD temp/RH |  | Enlarge/undercut slowly to raise; wax or bushing recovery if sharp. |
| KAV-B3-5H | VAL-ROOT | root B3 | 246.942 Hz |  | +/-25 cents P1, +/-10 cents P2 | TBD temp/RH |  | Trim foot shorter to raise pitch; rebuild/extend foot if sharp. |
| KAV-B3-5H | VAL-H1 | hole 1 offset +2 st | 277.183 Hz |  | +/-25 cents P1, +/-10 cents P2 | TBD temp/RH |  | Enlarge/undercut slowly to raise; wax or bushing recovery if sharp. |
| KAV-B3-5H | VAL-H2 | hole 2 offset +3 st | 293.665 Hz |  | +/-25 cents P1, +/-10 cents P2 | TBD temp/RH |  | Enlarge/undercut slowly to raise; wax or bushing recovery if sharp. |
| KAV-B3-5H | VAL-H3 | hole 3 offset +6 st | 349.228 Hz |  | +/-25 cents P1, +/-10 cents P2 | TBD temp/RH |  | Enlarge/undercut slowly to raise; wax or bushing recovery if sharp. |
| KAV-B3-5H | VAL-H4 | hole 4 offset +7 st | 369.994 Hz |  | +/-25 cents P1, +/-10 cents P2 | TBD temp/RH |  | Enlarge/undercut slowly to raise; wax or bushing recovery if sharp. |
| KAV-B3-5H | VAL-H5 | hole 5 offset +8 st | 391.995 Hz |  | +/-25 cents P1, +/-10 cents P2 | TBD temp/RH |  | Enlarge/undercut slowly to raise; wax or bushing recovery if sharp. |
| KAV-C4-5H | VAL-ROOT | root C4 | 261.626 Hz |  | +/-25 cents P1, +/-10 cents P2 | TBD temp/RH |  | Trim foot shorter to raise pitch; rebuild/extend foot if sharp. |
| KAV-C4-5H | VAL-H1 | hole 1 offset +2 st | 293.665 Hz |  | +/-25 cents P1, +/-10 cents P2 | TBD temp/RH |  | Enlarge/undercut slowly to raise; wax or bushing recovery if sharp. |
| KAV-C4-5H | VAL-H2 | hole 2 offset +3 st | 311.127 Hz |  | +/-25 cents P1, +/-10 cents P2 | TBD temp/RH |  | Enlarge/undercut slowly to raise; wax or bushing recovery if sharp. |
| KAV-C4-5H | VAL-H3 | hole 3 offset +6 st | 369.994 Hz |  | +/-25 cents P1, +/-10 cents P2 | TBD temp/RH |  | Enlarge/undercut slowly to raise; wax or bushing recovery if sharp. |
| KAV-C4-5H | VAL-H4 | hole 4 offset +7 st | 391.995 Hz |  | +/-25 cents P1, +/-10 cents P2 | TBD temp/RH |  | Enlarge/undercut slowly to raise; wax or bushing recovery if sharp. |
| KAV-C4-5H | VAL-H5 | hole 5 offset +8 st | 415.305 Hz |  | +/-25 cents P1, +/-10 cents P2 | TBD temp/RH |  | Enlarge/undercut slowly to raise; wax or bushing recovery if sharp. |
| KAV-A3-7H | VAL-ROOT | root A3 | 220.000 Hz |  | +/-25 cents P1, +/-10 cents P2 | TBD temp/RH |  | Trim foot shorter to raise pitch; rebuild/extend foot if sharp. |
| KAV-A3-7H | VAL-H1 | hole 1 offset +2 st | 246.942 Hz |  | +/-25 cents P1, +/-10 cents P2 | TBD temp/RH |  | Enlarge/undercut slowly to raise; wax or bushing recovery if sharp. |
| KAV-A3-7H | VAL-H2 | hole 2 offset +3 st | 261.626 Hz |  | +/-25 cents P1, +/-10 cents P2 | TBD temp/RH |  | Enlarge/undercut slowly to raise; wax or bushing recovery if sharp. |
| KAV-A3-7H | VAL-H3 | hole 3 offset +4 st | 277.183 Hz |  | +/-25 cents P1, +/-10 cents P2 | TBD temp/RH |  | Enlarge/undercut slowly to raise; wax or bushing recovery if sharp. |
| KAV-A3-7H | VAL-H4 | hole 4 offset +6 st | 311.127 Hz |  | +/-25 cents P1, +/-10 cents P2 | TBD temp/RH |  | Enlarge/undercut slowly to raise; wax or bushing recovery if sharp. |
| KAV-A3-7H | VAL-H5 | hole 5 offset +7 st | 329.628 Hz |  | +/-25 cents P1, +/-10 cents P2 | TBD temp/RH |  | Enlarge/undercut slowly to raise; wax or bushing recovery if sharp. |
| KAV-A3-7H | VAL-H6 | hole 6 offset +8 st | 349.228 Hz |  | +/-25 cents P1, +/-10 cents P2 | TBD temp/RH |  | Enlarge/undercut slowly to raise; wax or bushing recovery if sharp. |
| KAV-A3-7H | VAL-H7 | hole 7 offset +9 st | 369.994 Hz |  | +/-25 cents P1, +/-10 cents P2 | TBD temp/RH |  | Enlarge/undercut slowly to raise; wax or bushing recovery if sharp. |
| KAV-AS3-7H | VAL-ROOT | root A#3 | 233.082 Hz |  | +/-25 cents P1, +/-10 cents P2 | TBD temp/RH |  | Trim foot shorter to raise pitch; rebuild/extend foot if sharp. |
| KAV-AS3-7H | VAL-H1 | hole 1 offset +2 st | 261.626 Hz |  | +/-25 cents P1, +/-10 cents P2 | TBD temp/RH |  | Enlarge/undercut slowly to raise; wax or bushing recovery if sharp. |
| KAV-AS3-7H | VAL-H2 | hole 2 offset +3 st | 277.183 Hz |  | +/-25 cents P1, +/-10 cents P2 | TBD temp/RH |  | Enlarge/undercut slowly to raise; wax or bushing recovery if sharp. |
| KAV-AS3-7H | VAL-H3 | hole 3 offset +4 st | 293.665 Hz |  | +/-25 cents P1, +/-10 cents P2 | TBD temp/RH |  | Enlarge/undercut slowly to raise; wax or bushing recovery if sharp. |
| KAV-AS3-7H | VAL-H4 | hole 4 offset +6 st | 329.628 Hz |  | +/-25 cents P1, +/-10 cents P2 | TBD temp/RH |  | Enlarge/undercut slowly to raise; wax or bushing recovery if sharp. |
| KAV-AS3-7H | VAL-H5 | hole 5 offset +7 st | 349.228 Hz |  | +/-25 cents P1, +/-10 cents P2 | TBD temp/RH |  | Enlarge/undercut slowly to raise; wax or bushing recovery if sharp. |
| KAV-AS3-7H | VAL-H6 | hole 6 offset +8 st | 369.994 Hz |  | +/-25 cents P1, +/-10 cents P2 | TBD temp/RH |  | Enlarge/undercut slowly to raise; wax or bushing recovery if sharp. |
| KAV-AS3-7H | VAL-H7 | hole 7 offset +9 st | 391.995 Hz |  | +/-25 cents P1, +/-10 cents P2 | TBD temp/RH |  | Enlarge/undercut slowly to raise; wax or bushing recovery if sharp. |
| KAV-B3-7H | VAL-ROOT | root B3 | 246.942 Hz |  | +/-25 cents P1, +/-10 cents P2 | TBD temp/RH |  | Trim foot shorter to raise pitch; rebuild/extend foot if sharp. |
| KAV-B3-7H | VAL-H1 | hole 1 offset +2 st | 277.183 Hz |  | +/-25 cents P1, +/-10 cents P2 | TBD temp/RH |  | Enlarge/undercut slowly to raise; wax or bushing recovery if sharp. |
| KAV-B3-7H | VAL-H2 | hole 2 offset +3 st | 293.665 Hz |  | +/-25 cents P1, +/-10 cents P2 | TBD temp/RH |  | Enlarge/undercut slowly to raise; wax or bushing recovery if sharp. |
| KAV-B3-7H | VAL-H3 | hole 3 offset +4 st | 311.127 Hz |  | +/-25 cents P1, +/-10 cents P2 | TBD temp/RH |  | Enlarge/undercut slowly to raise; wax or bushing recovery if sharp. |
| KAV-B3-7H | VAL-H4 | hole 4 offset +6 st | 349.228 Hz |  | +/-25 cents P1, +/-10 cents P2 | TBD temp/RH |  | Enlarge/undercut slowly to raise; wax or bushing recovery if sharp. |
| KAV-B3-7H | VAL-H5 | hole 5 offset +7 st | 369.994 Hz |  | +/-25 cents P1, +/-10 cents P2 | TBD temp/RH |  | Enlarge/undercut slowly to raise; wax or bushing recovery if sharp. |
| KAV-B3-7H | VAL-H6 | hole 6 offset +8 st | 391.995 Hz |  | +/-25 cents P1, +/-10 cents P2 | TBD temp/RH |  | Enlarge/undercut slowly to raise; wax or bushing recovery if sharp. |
| KAV-B3-7H | VAL-H7 | hole 7 offset +9 st | 415.305 Hz |  | +/-25 cents P1, +/-10 cents P2 | TBD temp/RH |  | Enlarge/undercut slowly to raise; wax or bushing recovery if sharp. |
| ALG-AS3-J2 | VAL-ROOT | root A#3 | 233.082 Hz |  | +/-25 cents P1, +/-10 cents P2 | TBD temp/RH |  | Trim foot shorter to raise pitch; rebuild/extend foot if sharp. |
| ALG-AS3-J2 | VAL-H1 | hole 1 offset +2 st | 261.626 Hz |  | +/-25 cents P1, +/-10 cents P2 | TBD temp/RH |  | Enlarge/undercut slowly to raise; wax or bushing recovery if sharp. |
| ALG-AS3-J2 | VAL-H2 | hole 2 offset +4 st | 293.665 Hz |  | +/-25 cents P1, +/-10 cents P2 | TBD temp/RH |  | Enlarge/undercut slowly to raise; wax or bushing recovery if sharp. |
| ALG-AS3-J2 | VAL-H3 | hole 3 offset +7 st | 349.228 Hz |  | +/-25 cents P1, +/-10 cents P2 | TBD temp/RH |  | Enlarge/undercut slowly to raise; wax or bushing recovery if sharp. |
| ALG-AS3-J2 | VAL-H4 | hole 4 offset +9 st | 391.995 Hz |  | +/-25 cents P1, +/-10 cents P2 | TBD temp/RH |  | Enlarge/undercut slowly to raise; wax or bushing recovery if sharp. |
| ALG-AS3-J2 | VAL-H5 | hole 5 offset +11 st | 440.0 Hz |  | +/-25 cents P1, +/-10 cents P2 | TBD temp/RH |  | Enlarge/undercut slowly to raise; wax or bushing recovery if sharp. |
| ALG-AS3-J2 | VAL-H6 | hole 6 offset +12 st | 466.164 Hz |  | +/-25 cents P1, +/-10 cents P2 | TBD temp/RH |  | Enlarge/undercut slowly to raise; wax or bushing recovery if sharp. |
| ALG-AS3-SOLID | VAL-ROOT | root A#3 | 233.082 Hz |  | +/-25 cents P1, +/-10 cents P2 | TBD temp/RH |  | Trim foot shorter to raise pitch; rebuild/extend foot if sharp. |
| ALG-AS3-SOLID | VAL-H1 | hole 1 offset +2 st | 261.626 Hz |  | +/-25 cents P1, +/-10 cents P2 | TBD temp/RH |  | Enlarge/undercut slowly to raise; wax or bushing recovery if sharp. |
| ALG-AS3-SOLID | VAL-H2 | hole 2 offset +4 st | 293.665 Hz |  | +/-25 cents P1, +/-10 cents P2 | TBD temp/RH |  | Enlarge/undercut slowly to raise; wax or bushing recovery if sharp. |
| ALG-AS3-SOLID | VAL-H3 | hole 3 offset +7 st | 349.228 Hz |  | +/-25 cents P1, +/-10 cents P2 | TBD temp/RH |  | Enlarge/undercut slowly to raise; wax or bushing recovery if sharp. |
| ALG-AS3-SOLID | VAL-H4 | hole 4 offset +9 st | 391.995 Hz |  | +/-25 cents P1, +/-10 cents P2 | TBD temp/RH |  | Enlarge/undercut slowly to raise; wax or bushing recovery if sharp. |
| ALG-AS3-SOLID | VAL-H5 | hole 5 offset +11 st | 440.0 Hz |  | +/-25 cents P1, +/-10 cents P2 | TBD temp/RH |  | Enlarge/undercut slowly to raise; wax or bushing recovery if sharp. |
| ALG-AS3-SOLID | VAL-H6 | hole 6 offset +12 st | 466.164 Hz |  | +/-25 cents P1, +/-10 cents P2 | TBD temp/RH |  | Enlarge/undercut slowly to raise; wax or bushing recovery if sharp. |
| ALG-A3-J3 | VAL-ROOT | root A3 | 220.000 Hz |  | +/-25 cents P1, +/-10 cents P2 | TBD temp/RH |  | Trim foot shorter to raise pitch; rebuild/extend foot if sharp. |
| ALG-A3-J3 | VAL-H1 | hole 1 offset +2 st | 246.942 Hz |  | +/-25 cents P1, +/-10 cents P2 | TBD temp/RH |  | Enlarge/undercut slowly to raise; wax or bushing recovery if sharp. |
| ALG-A3-J3 | VAL-H2 | hole 2 offset +4 st | 277.183 Hz |  | +/-25 cents P1, +/-10 cents P2 | TBD temp/RH |  | Enlarge/undercut slowly to raise; wax or bushing recovery if sharp. |
| ALG-A3-J3 | VAL-H3 | hole 3 offset +7 st | 329.628 Hz |  | +/-25 cents P1, +/-10 cents P2 | TBD temp/RH |  | Enlarge/undercut slowly to raise; wax or bushing recovery if sharp. |
| ALG-A3-J3 | VAL-H4 | hole 4 offset +9 st | 369.994 Hz |  | +/-25 cents P1, +/-10 cents P2 | TBD temp/RH |  | Enlarge/undercut slowly to raise; wax or bushing recovery if sharp. |
| ALG-A3-J3 | VAL-H5 | hole 5 offset +11 st | 415.305 Hz |  | +/-25 cents P1, +/-10 cents P2 | TBD temp/RH |  | Enlarge/undercut slowly to raise; wax or bushing recovery if sharp. |
| ALG-A3-J3 | VAL-H6 | hole 6 offset +12 st | 440.0 Hz |  | +/-25 cents P1, +/-10 cents P2 | TBD temp/RH |  | Enlarge/undercut slowly to raise; wax or bushing recovery if sharp. |
| ALG-B3-SOLID | VAL-ROOT | root B3 | 246.942 Hz |  | +/-25 cents P1, +/-10 cents P2 | TBD temp/RH |  | Trim foot shorter to raise pitch; rebuild/extend foot if sharp. |
| ALG-B3-SOLID | VAL-H1 | hole 1 offset +2 st | 277.183 Hz |  | +/-25 cents P1, +/-10 cents P2 | TBD temp/RH |  | Enlarge/undercut slowly to raise; wax or bushing recovery if sharp. |
| ALG-B3-SOLID | VAL-H2 | hole 2 offset +4 st | 311.127 Hz |  | +/-25 cents P1, +/-10 cents P2 | TBD temp/RH |  | Enlarge/undercut slowly to raise; wax or bushing recovery if sharp. |
| ALG-B3-SOLID | VAL-H3 | hole 3 offset +7 st | 369.994 Hz |  | +/-25 cents P1, +/-10 cents P2 | TBD temp/RH |  | Enlarge/undercut slowly to raise; wax or bushing recovery if sharp. |
| ALG-B3-SOLID | VAL-H4 | hole 4 offset +9 st | 415.305 Hz |  | +/-25 cents P1, +/-10 cents P2 | TBD temp/RH |  | Enlarge/undercut slowly to raise; wax or bushing recovery if sharp. |
| ALG-B3-SOLID | VAL-H5 | hole 5 offset +11 st | 466.164 Hz |  | +/-25 cents P1, +/-10 cents P2 | TBD temp/RH |  | Enlarge/undercut slowly to raise; wax or bushing recovery if sharp. |
| ALG-B3-SOLID | VAL-H6 | hole 6 offset +12 st | 493.883 Hz |  | +/-25 cents P1, +/-10 cents P2 | TBD temp/RH |  | Enlarge/undercut slowly to raise; wax or bushing recovery if sharp. |
| ALL | VAL-FIPPLE | clean attack and stable octave jump | no choking at normal breath |  | subjective plus recording | TBD temp/RH |  | Adjust windway height, splitting edge sharpness, and window length. |
| DOUBLE | VAL-DRONE-BEAT | melody/drone pressure interaction | no severe stealing or beating unless intentional |  | recorded comparison | TBD temp/RH |  | Restrict windway, retune drone vent, or separate mouth inlets. |

## supplier-rfq.md

Supplier email/request-for-quote starter.

# Supplier RFQ Draft

Subject: Quote request for straight-grain woodwind blanks and optional ferrule stock

Hello,

I am building a small run of long fipple flutes and need stable straight-grain blanks suitable for bored woodwind bodies.

Please quote the following:

- 4 to 8 blanks, 1.25 to 1.50 in square or round, 30 to 38 in long.
- Species options: elder, locust, ash, maple, cherry, walnut, or similar stable hardwood.
- Moisture content and straightness/grain-runout information.
- Any longer stock suitable for 85-90 cm flute bodies.
- Optional thin-wall brass tube or hardwood ferrule stock around 1.25 to 1.40 in ID/OD range.

The blanks will be drilled or split-routed along the long axis, then turned and tuned, so straight grain and low checking risk matter more than figure.

Please include unit price, volume price, lead time, shipping estimate, and any recommended substitutes.

Thank you,
Tony Koop

## visual-bom-brief.md

Art direction for an image-forward visual BOM.

# Visual BOM Brief

Create one image-forward BOM plate with:

- hero view of a kaval, an Alghosazi, and the fipple-head section;
- item rows for body blank, fipple plug, cork/ferrule, drilling template, finish, and validation tools;
- callouts that distinguish make vs buy parts;
- source status labels: verified price, spec only, or shop stock.

Image sources:

- Use real shop photos after P0/P1 prototypes exist.
- Until then, use `images/hero.png` and the SVG drawings as concept placeholders.
- Do not use vendor or Fujara Flutes photos directly in the BOM without permission.

## wolfram-starter.wl

Wolfram starter for physics, optimization, visualization, and validation.

```wolfram
(* Kaval + Alghosazi starter. Full v4.2 packet source is in wolfram/kaval-alghosazi-flutes-wolfram-model.wl after generation. *)
ClearAll["Global`*"];
cInPerSec = 13552;
freqFromMidi[midi_, a4_: 440] := a4*2^((midi - 69)/12);
openPipeLeff[f_] := cInPerSec/(2*f);
holeFromLabium[labiumToFoot_, semitoneOffset_] := labiumToFoot*2^(-semitoneOffset/12);
centsError[measured_, target_] := 1200*Log[2, measured/target];
```

## README.md

Project artifact.

# Kaval + Alghosazi Fipple Flutes

This repository is a build-ready design packet for two related long fipple flutes:

- a **Moldavian/Romanian-style fipple kaval** family, including 5-hole, 7-hole, two-piece, and double-drone options;
- a **fipple Alghosazi** family inspired by the Anasazi/Basketmaker long-flute lineage, with an easier fipple head and a rear thumb hole.

The head design intentionally borrows from Tony's `fujara` CAD: the player blows into an end mouth inlet, the air travels through a controlled internal flue, and sound is made at a side **true sound window** and splitting edge. The head is not copied from a commercial maker; it is a Tony-shop fujara/NAF hybrid that can be tuned and rebuilt.

## Build First

Start with these prototypes:

| Prototype | Why |
| --- | --- |
| `KAV-A3-5H` | Best first kaval: published 74 cm precedent, forgiving length, 5-hole pattern. |
| `ALG-AS3-J2` | Best first Alghosazi: published 82 cm two-piece precedent, thumb-hole layout. |
| `P0-FIPPLE-HEAD` | Scrap head tile that proves the mouth inlet, flue, window, and splitting edge before a full body. |

## File Map

| File | Use |
| --- | --- |
| `Kaval-Alghosazi-Design.xlsx` | Parametric workbook: family spec, formulas, hole schedules, fipple inputs. |
| `design.md` | Acoustic model, cultural/source notes, assumptions, and build intent. |
| `family-spec.csv` | Row-per-member design table used by drawing/CAD generators. |
| `hole-schedule.csv` | First-pass hole positions measured from labium and foot. |
| `bom.csv`, `sourcing.csv`, `cut-list.csv` | Procurement and stock prep. |
| `assembly-manual.md` | Shop sequence from fipple tile through tuning. |
| `drawings/` | SVG manufacturing drawings and head/joint details. |
| `cad/` | OpenSCAD and SolidWorks starter handoff files. |
| `cnc/` | v4.2 operation plan and setup sheet. |
| `validation.csv` | Tuning and empirical correction log. |
| `capstone-deck.pptx`, `print-packet.pdf`, `site/index.html` | Presentation, shop print, and build-log deliverables. |

## Status

This is a first-pass engineering packet. Dimensions are parametric and source-backed where possible, but the fipple/sound-window correction is marked as a measured-prototype variable, not a borrowed NAF K2 correction.

## Attribution

The kaval references come from Moldavian/Romanian shepherd-flute practice; the Alghosazi references point toward Anasazi/Basketmaker flute replicas and contemporary adaptations. This packet is a modern shop design by Tony Koop, built with respect for those lineages and explicit source notes in `sources.md`.

## alghosazi-hole-schedule.csv

Project artifact.

| member_id | instrument | hole_no_from_foot | offset_st | target_hz | x_from_labium_in | x_from_foot_in | starter_drill_in | target_final_dia_in | orientation | formula |
| --- | --- | --- | --- | --- | --- | --- | --- | --- | --- | --- |
| ALG-AS3-J2 | Fipple Alghosazi | 1 | 2 | 261.626 | 27.158 | 3.326 | 0.1875 | 0.2500 | front | x_from_labium = labium_to_foot * 2^(-offset_st/12); tune upward by enlarging |
| ALG-AS3-J2 | Fipple Alghosazi | 2 | 4 | 293.665 | 24.195 | 6.289 | 0.1875 | 0.2500 | front | x_from_labium = labium_to_foot * 2^(-offset_st/12); tune upward by enlarging |
| ALG-AS3-J2 | Fipple Alghosazi | 3 | 7 | 349.228 | 20.345 | 10.138 | 0.1875 | 0.2500 | front | x_from_labium = labium_to_foot * 2^(-offset_st/12); tune upward by enlarging |
| ALG-AS3-J2 | Fipple Alghosazi | 4 | 9 | 391.995 | 18.126 | 12.358 | 0.2188 | 0.3125 | front | x_from_labium = labium_to_foot * 2^(-offset_st/12); tune upward by enlarging |
| ALG-AS3-J2 | Fipple Alghosazi | 5 | 11 | 440.0 | 16.148 | 14.335 | 0.2188 | 0.3125 | front | x_from_labium = labium_to_foot * 2^(-offset_st/12); tune upward by enlarging |
| ALG-AS3-J2 | Fipple Alghosazi | 6 | 12 | 466.164 | 15.242 | 15.242 | 0.2188 | 0.3125 | back thumb | x_from_labium = labium_to_foot * 2^(-offset_st/12); tune upward by enlarging |
| ALG-AS3-SOLID | Fipple Alghosazi | 1 | 2 | 261.626 | 28.21 | 3.455 | 0.1875 | 0.2500 | front | x_from_labium = labium_to_foot * 2^(-offset_st/12); tune upward by enlarging |
| ALG-AS3-SOLID | Fipple Alghosazi | 2 | 4 | 293.665 | 25.132 | 6.532 | 0.1875 | 0.2500 | front | x_from_labium = labium_to_foot * 2^(-offset_st/12); tune upward by enlarging |
| ALG-AS3-SOLID | Fipple Alghosazi | 3 | 7 | 349.228 | 21.134 | 10.531 | 0.1875 | 0.2500 | front | x_from_labium = labium_to_foot * 2^(-offset_st/12); tune upward by enlarging |
| ALG-AS3-SOLID | Fipple Alghosazi | 4 | 9 | 391.995 | 18.828 | 12.837 | 0.2188 | 0.3125 | front | x_from_labium = labium_to_foot * 2^(-offset_st/12); tune upward by enlarging |
| ALG-AS3-SOLID | Fipple Alghosazi | 5 | 11 | 440.0 | 16.774 | 14.891 | 0.2188 | 0.3125 | front | x_from_labium = labium_to_foot * 2^(-offset_st/12); tune upward by enlarging |
| ALG-AS3-SOLID | Fipple Alghosazi | 6 | 12 | 466.164 | 15.832 | 15.832 | 0.2188 | 0.3125 | back thumb | x_from_labium = labium_to_foot * 2^(-offset_st/12); tune upward by enlarging |
| ALG-A3-J3 | Fipple Alghosazi | 1 | 2 | 246.942 | 24.045 | 2.945 | 0.1875 | 0.2500 | front | x_from_labium = labium_to_foot * 2^(-offset_st/12); tune upward by enlarging |
| ALG-A3-J3 | Fipple Alghosazi | 2 | 4 | 277.183 | 21.422 | 5.568 | 0.1875 | 0.2500 | front | x_from_labium = labium_to_foot * 2^(-offset_st/12); tune upward by enlarging |
| ALG-A3-J3 | Fipple Alghosazi | 3 | 7 | 329.628 | 18.014 | 8.976 | 0.1875 | 0.2500 | front | x_from_labium = labium_to_foot * 2^(-offset_st/12); tune upward by enlarging |
| ALG-A3-J3 | Fipple Alghosazi | 4 | 9 | 369.994 | 16.048 | 10.942 | 0.2188 | 0.3125 | front | x_from_labium = labium_to_foot * 2^(-offset_st/12); tune upward by enlarging |
| ALG-A3-J3 | Fipple Alghosazi | 5 | 11 | 415.305 | 14.298 | 12.693 | 0.2188 | 0.3125 | front | x_from_labium = labium_to_foot * 2^(-offset_st/12); tune upward by enlarging |
| ALG-A3-J3 | Fipple Alghosazi | 6 | 12 | 440.0 | 13.495 | 13.495 | 0.2188 | 0.3125 | back thumb | x_from_labium = labium_to_foot * 2^(-offset_st/12); tune upward by enlarging |
| ALG-B3-SOLID | Fipple Alghosazi | 1 | 2 | 277.183 | 23.082 | 2.827 | 0.1875 | 0.2500 | front | x_from_labium = labium_to_foot * 2^(-offset_st/12); tune upward by enlarging |
| ALG-B3-SOLID | Fipple Alghosazi | 2 | 4 | 311.127 | 20.564 | 5.345 | 0.1875 | 0.2500 | front | x_from_labium = labium_to_foot * 2^(-offset_st/12); tune upward by enlarging |
| ALG-B3-SOLID | Fipple Alghosazi | 3 | 7 | 369.994 | 17.292 | 8.617 | 0.1875 | 0.2500 | front | x_from_labium = labium_to_foot * 2^(-offset_st/12); tune upward by enlarging |
| ALG-B3-SOLID | Fipple Alghosazi | 4 | 9 | 415.305 | 15.406 | 10.503 | 0.2188 | 0.3125 | front | x_from_labium = labium_to_foot * 2^(-offset_st/12); tune upward by enlarging |
| ALG-B3-SOLID | Fipple Alghosazi | 5 | 11 | 466.164 | 13.725 | 12.184 | 0.2188 | 0.3125 | front | x_from_labium = labium_to_foot * 2^(-offset_st/12); tune upward by enlarging |
| ALG-B3-SOLID | Fipple Alghosazi | 6 | 12 | 493.883 | 12.955 | 12.955 | 0.2188 | 0.3125 | back thumb | x_from_labium = labium_to_foot * 2^(-offset_st/12); tune upward by enlarging |

## double-drone-spec.csv

Project artifact.

| assembly_id | melody_side | drone_side | windways | body_strategy | overall_length_in | validation |
| --- | --- | --- | --- | --- | --- | --- |
| KAVGH-A3-DOUBLE | KAV-A3-5H | A3 drone with rear thumb vent raising to B3 | 2 | two separate bores lashed or mechanically joined; melody kaval removable | 29.1 to 31.0 | Tune melody alone, drone alone, then both together for beating and pressure interaction. |
| DALG-AS3-DOUBLE | ALG-AS3-J2 or ALG-AS3-SOLID | reedy/natural-harmonic drone bore with independent windway | 2 | parallel-tube double flute with two mouth inlets; each side playable separately | 33.1 | Record both windways independently and together; check pressure stealing between ducts. |

## family-spec.csv

Project artifact.

| member_id | instrument | subtype | target_note | target_hz | midi | scale_label | hole_count | hole_offsets_st | bore_id_in | body_od_in | wall_in | total_length_cm | total_length_in | top_to_window_in | labium_to_foot_in | open_pipe_leff_in | estimated_sound_window_correction_in | tuning_delta_interpretation | chamber_to_bore | wood_species | construction | source_basis | done_bar_ref | notes |
| --- | --- | --- | --- | --- | --- | --- | --- | --- | --- | --- | --- | --- | --- | --- | --- | --- | --- | --- | --- | --- | --- | --- | --- | --- |
| KAV-GS3-5H | Fipple Kaval | 5-hole Moldavian/Romanian | G#3 | 207.652 | 56 | Kaval gypsy mode: 0,2,3,6,7,8 semitones | 5 | 2 3 6 7 8 | 0.8750 | 1.3750 | 0.2500 | 79.0 | 31.102 | 1.600 | 29.502 | 32.631 | 3.129 | positive: needs fipple/window end correction or added acoustic length | 33.7 | Locust or elder | solid or split blank; optional two-piece joint | Fujara Flutes observed G# kaval length 79 cm | fujara + flutes + pistalka | Longest 5-hole starter; use as low-voice reference. |
| KAV-A3-5H | Fipple Kaval | 5-hole Moldavian/Romanian | A3 | 220.000 | 57 | Kaval gypsy mode: 0,2,3,6,7,8 semitones | 5 | 2 3 6 7 8 | 0.8750 | 1.3750 | 0.2500 | 74.0 | 29.134 | 1.600 | 27.534 | 30.800 | 3.266 | positive: needs fipple/window end correction or added acoustic length | 31.5 | Elder | two-piece optional hand-cut joint | Fujara Flutes observed A kaval length 74 cm | fujara + flutes + pistalka | Recommended first kaval because length, bore, and hand span are forgiving. |
| KAV-B3-5H | Fipple Kaval | 5-hole Moldavian/Romanian | B3 | 246.942 | 59 | Kaval gypsy mode: 0,2,3,6,7,8 semitones | 5 | 2 3 6 7 8 | 0.8125 | 1.3125 | 0.2500 | 67.0 | 26.378 | 1.500 | 24.878 | 27.440 | 2.562 | positive: needs fipple/window end correction or added acoustic length | 30.6 | Elder | solid split blank | Fujara Flutes observed B kaval length 67 cm | fujara + flutes + pistalka | Compact 5-hole version; tighter fipple tolerances. |
| KAV-C4-5H | Fipple Kaval | 5-hole Moldavian/Romanian | C4 | 261.626 | 60 | Kaval gypsy mode: 0,2,3,6,7,8 semitones | 5 | 2 3 6 7 8 | 0.7500 | 1.2500 | 0.2500 | 62.0 | 24.409 | 1.450 | 22.959 | 25.900 | 2.940 | positive: needs fipple/window end correction or added acoustic length | 30.6 | Elder, maple, or cherry | solid split blank | Fujara Flutes observed C kaval length 62 cm | fujara + flutes + pistalka | Smallest 5-hole kaval; good for fipple/head trials. |
| KAV-A3-7H | Fipple Kaval | 7-hole expanded Moldavian | A3 | 220.000 | 57 | Expanded kaval: 0,2,3,4,6,7,8,9 semitones | 7 | 2 3 4 6 7 8 9 | 0.8750 | 1.4000 | 0.2625 | 90.0 | 35.433 | 1.650 | 33.783 | 30.800 | -2.983 | negative: observed source length is overlong for this nominal root; trim foot or reassess key naming | 38.6 | Elder | solid split blank | Fujara Flutes observed 7-hole A kaval length 90 cm | fujara + flutes + pistalka | Expanded note set; lower holes may be covered with finger bases. |
| KAV-AS3-7H | Fipple Kaval | 7-hole expanded Moldavian | A#3 | 233.082 | 58 | Expanded kaval: 0,2,3,4,6,7,8,9 semitones | 7 | 2 3 4 6 7 8 9 | 0.8750 | 1.4000 | 0.2625 | 85.0 | 33.465 | 1.650 | 31.815 | 29.071 | -2.743 | negative: observed source length is overlong for this nominal root; trim foot or reassess key naming | 36.4 | Dogwood or elder | two-piece optional hand-cut joint | Fujara Flutes observed 7-hole A# kaval length 85 cm | fujara + flutes + pistalka | Good two-piece test because the published example is collapsible. |
| KAV-B3-7H | Fipple Kaval | 7-hole expanded Moldavian | B3 | 246.942 | 59 | Expanded kaval: 0,2,3,4,6,7,8,9 semitones | 7 | 2 3 4 6 7 8 9 | 0.8125 | 1.3125 | 0.2500 | 69.0 | 27.165 | 1.500 | 25.665 | 27.440 | 1.774 | positive: needs fipple/window end correction or added acoustic length | 31.6 | Elder | solid split blank | Fujara Flutes observed 7-hole B kaval length 69 cm | fujara + flutes + pistalka | Compact 7-hole version; validate hand position before final hole diameters. |
| ALG-AS3-J2 | Fipple Alghosazi | Anasazi-derived with thumb hole | A#3 | 233.082 | 58 | Anasazi-derived: 0,2,4,7,9,11,12 semitones | 6 | 2 4 7 9 11 12 | 0.8750 | 1.3750 | 0.2500 | 82.0 | 32.283 | 1.800 | 30.483 | 29.071 | -1.412 | negative: observed source length is overlong for this nominal root; trim foot or reassess key naming | 34.8 | Ash | two-piece hand-cut joint | Fujara Flutes observed A# Alghosazi length 82 cm | fujara + flutes + pistalka | Recommended first Alghosazi; published example uses a collapsible joint. |
| ALG-AS3-SOLID | Fipple Alghosazi | Anasazi-derived with thumb hole | A#3 | 233.082 | 58 | Anasazi-derived: 0,2,4,7,9,11,12 semitones | 6 | 2 4 7 9 11 12 | 0.8750 | 1.3750 | 0.2500 | 85.0 | 33.465 | 1.800 | 31.665 | 29.071 | -2.593 | negative: observed source length is overlong for this nominal root; trim foot or reassess key naming | 36.2 | Locust | solid split blank | Fujara Flutes observed solid A# Alghosazi length 85 cm | fujara + flutes + pistalka | Solid-body alternate for comparing joint vs no-joint response. |
| ALG-A3-J3 | Fipple Alghosazi | Anasazi-derived with thumb hole | A3 | 220.000 | 57 | Anasazi-derived: 0,2,4,7,9,11,12 semitones | 6 | 2 4 7 9 11 12 | 0.8750 | 1.3750 | 0.2500 | 73.0 | 28.740 | 1.750 | 26.990 | 30.800 | 3.810 | positive: needs fipple/window end correction or added acoustic length | 30.8 | Oak | three-piece hand-cut joint | Fujara Flutes observed A Alghosazi length 73 cm | fujara + flutes + pistalka | Use as the modular joint stress test. |
| ALG-B3-SOLID | Fipple Alghosazi | Anasazi-derived with thumb hole | B3 | 246.942 | 59 | Anasazi-derived: 0,2,4,7,9,11,12 semitones | 6 | 2 4 7 9 11 12 | 0.8125 | 1.3125 | 0.2500 | 70.0 | 27.559 | 1.650 | 25.909 | 27.440 | 1.531 | positive: needs fipple/window end correction or added acoustic length | 31.9 | Elder or maple | solid split blank | Fujara Flutes observed B Alghosazi length 70 cm | fujara + flutes + pistalka | Compact Alghosazi; top thumb hole needs ergonomic mockup. |

## hole-schedule.csv

Project artifact.

| member_id | instrument | hole_no_from_foot | offset_st | target_hz | x_from_labium_in | x_from_foot_in | starter_drill_in | target_final_dia_in | orientation | formula |
| --- | --- | --- | --- | --- | --- | --- | --- | --- | --- | --- |
| KAV-GS3-5H | Fipple Kaval | 1 | 2 | 233.082 | 26.284 | 3.219 | 0.1875 | 0.2500 | front | x_from_labium = labium_to_foot * 2^(-offset_st/12); tune upward by enlarging |
| KAV-GS3-5H | Fipple Kaval | 2 | 3 | 246.942 | 24.808 | 4.694 | 0.1875 | 0.2500 | front | x_from_labium = labium_to_foot * 2^(-offset_st/12); tune upward by enlarging |
| KAV-GS3-5H | Fipple Kaval | 3 | 6 | 293.665 | 20.861 | 8.641 | 0.2188 | 0.3000 | front | x_from_labium = labium_to_foot * 2^(-offset_st/12); tune upward by enlarging |
| KAV-GS3-5H | Fipple Kaval | 4 | 7 | 311.127 | 19.69 | 9.812 | 0.2188 | 0.3000 | front | x_from_labium = labium_to_foot * 2^(-offset_st/12); tune upward by enlarging |
| KAV-GS3-5H | Fipple Kaval | 5 | 8 | 329.628 | 18.585 | 10.917 | 0.2188 | 0.3000 | front | x_from_labium = labium_to_foot * 2^(-offset_st/12); tune upward by enlarging |
| KAV-A3-5H | Fipple Kaval | 1 | 2 | 246.942 | 24.53 | 3.004 | 0.1875 | 0.2500 | front | x_from_labium = labium_to_foot * 2^(-offset_st/12); tune upward by enlarging |
| KAV-A3-5H | Fipple Kaval | 2 | 3 | 261.626 | 23.153 | 4.381 | 0.1875 | 0.2500 | front | x_from_labium = labium_to_foot * 2^(-offset_st/12); tune upward by enlarging |
| KAV-A3-5H | Fipple Kaval | 3 | 6 | 311.127 | 19.469 | 8.064 | 0.2188 | 0.3000 | front | x_from_labium = labium_to_foot * 2^(-offset_st/12); tune upward by enlarging |
| KAV-A3-5H | Fipple Kaval | 4 | 7 | 329.628 | 18.377 | 9.157 | 0.2188 | 0.3000 | front | x_from_labium = labium_to_foot * 2^(-offset_st/12); tune upward by enlarging |
| KAV-A3-5H | Fipple Kaval | 5 | 8 | 349.228 | 17.345 | 10.189 | 0.2188 | 0.3000 | front | x_from_labium = labium_to_foot * 2^(-offset_st/12); tune upward by enlarging |
| KAV-B3-5H | Fipple Kaval | 1 | 2 | 277.183 | 22.164 | 2.714 | 0.1875 | 0.2500 | front | x_from_labium = labium_to_foot * 2^(-offset_st/12); tune upward by enlarging |
| KAV-B3-5H | Fipple Kaval | 2 | 3 | 293.665 | 20.92 | 3.958 | 0.1875 | 0.2500 | front | x_from_labium = labium_to_foot * 2^(-offset_st/12); tune upward by enlarging |
| KAV-B3-5H | Fipple Kaval | 3 | 6 | 349.228 | 17.591 | 7.287 | 0.2188 | 0.3000 | front | x_from_labium = labium_to_foot * 2^(-offset_st/12); tune upward by enlarging |
| KAV-B3-5H | Fipple Kaval | 4 | 7 | 369.994 | 16.604 | 8.274 | 0.2188 | 0.3000 | front | x_from_labium = labium_to_foot * 2^(-offset_st/12); tune upward by enlarging |
| KAV-B3-5H | Fipple Kaval | 5 | 8 | 391.995 | 15.672 | 9.206 | 0.2188 | 0.3000 | front | x_from_labium = labium_to_foot * 2^(-offset_st/12); tune upward by enlarging |
| KAV-C4-5H | Fipple Kaval | 1 | 2 | 293.665 | 20.455 | 2.505 | 0.1875 | 0.2500 | front | x_from_labium = labium_to_foot * 2^(-offset_st/12); tune upward by enlarging |
| KAV-C4-5H | Fipple Kaval | 2 | 3 | 311.127 | 19.307 | 3.653 | 0.1875 | 0.2500 | front | x_from_labium = labium_to_foot * 2^(-offset_st/12); tune upward by enlarging |
| KAV-C4-5H | Fipple Kaval | 3 | 6 | 369.994 | 16.235 | 6.725 | 0.2188 | 0.3000 | front | x_from_labium = labium_to_foot * 2^(-offset_st/12); tune upward by enlarging |
| KAV-C4-5H | Fipple Kaval | 4 | 7 | 391.995 | 15.324 | 7.636 | 0.2188 | 0.3000 | front | x_from_labium = labium_to_foot * 2^(-offset_st/12); tune upward by enlarging |
| KAV-C4-5H | Fipple Kaval | 5 | 8 | 415.305 | 14.464 | 8.496 | 0.2188 | 0.3000 | front | x_from_labium = labium_to_foot * 2^(-offset_st/12); tune upward by enlarging |
| KAV-A3-7H | Fipple Kaval | 1 | 2 | 246.942 | 30.097 | 3.686 | 0.1875 | 0.2500 | front | x_from_labium = labium_to_foot * 2^(-offset_st/12); tune upward by enlarging |
| KAV-A3-7H | Fipple Kaval | 2 | 3 | 261.626 | 28.408 | 5.375 | 0.1875 | 0.2500 | front | x_from_labium = labium_to_foot * 2^(-offset_st/12); tune upward by enlarging |
| KAV-A3-7H | Fipple Kaval | 3 | 4 | 277.183 | 26.814 | 6.969 | 0.2188 | 0.3000 | front | x_from_labium = labium_to_foot * 2^(-offset_st/12); tune upward by enlarging |
| KAV-A3-7H | Fipple Kaval | 4 | 6 | 311.127 | 23.888 | 9.895 | 0.2188 | 0.3000 | front | x_from_labium = labium_to_foot * 2^(-offset_st/12); tune upward by enlarging |
| KAV-A3-7H | Fipple Kaval | 5 | 7 | 329.628 | 22.547 | 11.236 | 0.2188 | 0.3000 | front | x_from_labium = labium_to_foot * 2^(-offset_st/12); tune upward by enlarging |
| KAV-A3-7H | Fipple Kaval | 6 | 8 | 349.228 | 21.282 | 12.501 | 0.2188 | 0.3000 | front | x_from_labium = labium_to_foot * 2^(-offset_st/12); tune upward by enlarging |
| KAV-A3-7H | Fipple Kaval | 7 | 9 | 369.994 | 20.088 | 13.696 | 0.2188 | 0.3000 | front | x_from_labium = labium_to_foot * 2^(-offset_st/12); tune upward by enlarging |
| KAV-AS3-7H | Fipple Kaval | 1 | 2 | 261.626 | 28.344 | 3.471 | 0.1875 | 0.2500 | front | x_from_labium = labium_to_foot * 2^(-offset_st/12); tune upward by enlarging |
| KAV-AS3-7H | Fipple Kaval | 2 | 3 | 277.183 | 26.753 | 5.062 | 0.1875 | 0.2500 | front | x_from_labium = labium_to_foot * 2^(-offset_st/12); tune upward by enlarging |
| KAV-AS3-7H | Fipple Kaval | 3 | 4 | 293.665 | 25.251 | 6.563 | 0.2188 | 0.3000 | front | x_from_labium = labium_to_foot * 2^(-offset_st/12); tune upward by enlarging |
| KAV-AS3-7H | Fipple Kaval | 4 | 6 | 329.628 | 22.496 | 9.318 | 0.2188 | 0.3000 | front | x_from_labium = labium_to_foot * 2^(-offset_st/12); tune upward by enlarging |
| KAV-AS3-7H | Fipple Kaval | 5 | 7 | 349.228 | 21.234 | 10.581 | 0.2188 | 0.3000 | front | x_from_labium = labium_to_foot * 2^(-offset_st/12); tune upward by enlarging |
| KAV-AS3-7H | Fipple Kaval | 6 | 8 | 369.994 | 20.042 | 11.773 | 0.2188 | 0.3000 | front | x_from_labium = labium_to_foot * 2^(-offset_st/12); tune upward by enlarging |
| KAV-AS3-7H | Fipple Kaval | 7 | 9 | 391.995 | 18.917 | 12.898 | 0.2188 | 0.3000 | front | x_from_labium = labium_to_foot * 2^(-offset_st/12); tune upward by enlarging |
| KAV-B3-7H | Fipple Kaval | 1 | 2 | 277.183 | 22.865 | 2.8 | 0.1875 | 0.2500 | front | x_from_labium = labium_to_foot * 2^(-offset_st/12); tune upward by enlarging |
| KAV-B3-7H | Fipple Kaval | 2 | 3 | 293.665 | 21.582 | 4.083 | 0.1875 | 0.2500 | front | x_from_labium = labium_to_foot * 2^(-offset_st/12); tune upward by enlarging |
| KAV-B3-7H | Fipple Kaval | 3 | 4 | 311.127 | 20.371 | 5.295 | 0.2188 | 0.3000 | front | x_from_labium = labium_to_foot * 2^(-offset_st/12); tune upward by enlarging |
| KAV-B3-7H | Fipple Kaval | 4 | 6 | 349.228 | 18.148 | 7.517 | 0.2188 | 0.3000 | front | x_from_labium = labium_to_foot * 2^(-offset_st/12); tune upward by enlarging |
| KAV-B3-7H | Fipple Kaval | 5 | 7 | 369.994 | 17.13 | 8.536 | 0.2188 | 0.3000 | front | x_from_labium = labium_to_foot * 2^(-offset_st/12); tune upward by enlarging |
| KAV-B3-7H | Fipple Kaval | 6 | 8 | 391.995 | 16.168 | 9.497 | 0.2188 | 0.3000 | front | x_from_labium = labium_to_foot * 2^(-offset_st/12); tune upward by enlarging |
| KAV-B3-7H | Fipple Kaval | 7 | 9 | 415.305 | 15.261 | 10.405 | 0.2188 | 0.3000 | front | x_from_labium = labium_to_foot * 2^(-offset_st/12); tune upward by enlarging |
| ALG-AS3-J2 | Fipple Alghosazi | 1 | 2 | 261.626 | 27.158 | 3.326 | 0.1875 | 0.2500 | front | x_from_labium = labium_to_foot * 2^(-offset_st/12); tune upward by enlarging |
| ALG-AS3-J2 | Fipple Alghosazi | 2 | 4 | 293.665 | 24.195 | 6.289 | 0.1875 | 0.2500 | front | x_from_labium = labium_to_foot * 2^(-offset_st/12); tune upward by enlarging |
| ALG-AS3-J2 | Fipple Alghosazi | 3 | 7 | 349.228 | 20.345 | 10.138 | 0.1875 | 0.2500 | front | x_from_labium = labium_to_foot * 2^(-offset_st/12); tune upward by enlarging |
| ALG-AS3-J2 | Fipple Alghosazi | 4 | 9 | 391.995 | 18.126 | 12.358 | 0.2188 | 0.3125 | front | x_from_labium = labium_to_foot * 2^(-offset_st/12); tune upward by enlarging |
| ALG-AS3-J2 | Fipple Alghosazi | 5 | 11 | 440.0 | 16.148 | 14.335 | 0.2188 | 0.3125 | front | x_from_labium = labium_to_foot * 2^(-offset_st/12); tune upward by enlarging |
| ALG-AS3-J2 | Fipple Alghosazi | 6 | 12 | 466.164 | 15.242 | 15.242 | 0.2188 | 0.3125 | back thumb | x_from_labium = labium_to_foot * 2^(-offset_st/12); tune upward by enlarging |
| ALG-AS3-SOLID | Fipple Alghosazi | 1 | 2 | 261.626 | 28.21 | 3.455 | 0.1875 | 0.2500 | front | x_from_labium = labium_to_foot * 2^(-offset_st/12); tune upward by enlarging |
| ALG-AS3-SOLID | Fipple Alghosazi | 2 | 4 | 293.665 | 25.132 | 6.532 | 0.1875 | 0.2500 | front | x_from_labium = labium_to_foot * 2^(-offset_st/12); tune upward by enlarging |
| ALG-AS3-SOLID | Fipple Alghosazi | 3 | 7 | 349.228 | 21.134 | 10.531 | 0.1875 | 0.2500 | front | x_from_labium = labium_to_foot * 2^(-offset_st/12); tune upward by enlarging |
| ALG-AS3-SOLID | Fipple Alghosazi | 4 | 9 | 391.995 | 18.828 | 12.837 | 0.2188 | 0.3125 | front | x_from_labium = labium_to_foot * 2^(-offset_st/12); tune upward by enlarging |
| ALG-AS3-SOLID | Fipple Alghosazi | 5 | 11 | 440.0 | 16.774 | 14.891 | 0.2188 | 0.3125 | front | x_from_labium = labium_to_foot * 2^(-offset_st/12); tune upward by enlarging |
| ALG-AS3-SOLID | Fipple Alghosazi | 6 | 12 | 466.164 | 15.832 | 15.832 | 0.2188 | 0.3125 | back thumb | x_from_labium = labium_to_foot * 2^(-offset_st/12); tune upward by enlarging |
| ALG-A3-J3 | Fipple Alghosazi | 1 | 2 | 246.942 | 24.045 | 2.945 | 0.1875 | 0.2500 | front | x_from_labium = labium_to_foot * 2^(-offset_st/12); tune upward by enlarging |
| ALG-A3-J3 | Fipple Alghosazi | 2 | 4 | 277.183 | 21.422 | 5.568 | 0.1875 | 0.2500 | front | x_from_labium = labium_to_foot * 2^(-offset_st/12); tune upward by enlarging |
| ALG-A3-J3 | Fipple Alghosazi | 3 | 7 | 329.628 | 18.014 | 8.976 | 0.1875 | 0.2500 | front | x_from_labium = labium_to_foot * 2^(-offset_st/12); tune upward by enlarging |
| ALG-A3-J3 | Fipple Alghosazi | 4 | 9 | 369.994 | 16.048 | 10.942 | 0.2188 | 0.3125 | front | x_from_labium = labium_to_foot * 2^(-offset_st/12); tune upward by enlarging |
| ALG-A3-J3 | Fipple Alghosazi | 5 | 11 | 415.305 | 14.298 | 12.693 | 0.2188 | 0.3125 | front | x_from_labium = labium_to_foot * 2^(-offset_st/12); tune upward by enlarging |
| ALG-A3-J3 | Fipple Alghosazi | 6 | 12 | 440.0 | 13.495 | 13.495 | 0.2188 | 0.3125 | back thumb | x_from_labium = labium_to_foot * 2^(-offset_st/12); tune upward by enlarging |
| ALG-B3-SOLID | Fipple Alghosazi | 1 | 2 | 277.183 | 23.082 | 2.827 | 0.1875 | 0.2500 | front | x_from_labium = labium_to_foot * 2^(-offset_st/12); tune upward by enlarging |
| ALG-B3-SOLID | Fipple Alghosazi | 2 | 4 | 311.127 | 20.564 | 5.345 | 0.1875 | 0.2500 | front | x_from_labium = labium_to_foot * 2^(-offset_st/12); tune upward by enlarging |
| ALG-B3-SOLID | Fipple Alghosazi | 3 | 7 | 369.994 | 17.292 | 8.617 | 0.1875 | 0.2500 | front | x_from_labium = labium_to_foot * 2^(-offset_st/12); tune upward by enlarging |
| ALG-B3-SOLID | Fipple Alghosazi | 4 | 9 | 415.305 | 15.406 | 10.503 | 0.2188 | 0.3125 | front | x_from_labium = labium_to_foot * 2^(-offset_st/12); tune upward by enlarging |
| ALG-B3-SOLID | Fipple Alghosazi | 5 | 11 | 466.164 | 13.725 | 12.184 | 0.2188 | 0.3125 | front | x_from_labium = labium_to_foot * 2^(-offset_st/12); tune upward by enlarging |
| ALG-B3-SOLID | Fipple Alghosazi | 6 | 12 | 493.883 | 12.955 | 12.955 | 0.2188 | 0.3125 | back thumb | x_from_labium = labium_to_foot * 2^(-offset_st/12); tune upward by enlarging |

## kaval-hole-schedule.csv

Project artifact.

| member_id | instrument | hole_no_from_foot | offset_st | target_hz | x_from_labium_in | x_from_foot_in | starter_drill_in | target_final_dia_in | orientation | formula |
| --- | --- | --- | --- | --- | --- | --- | --- | --- | --- | --- |
| KAV-GS3-5H | Fipple Kaval | 1 | 2 | 233.082 | 26.284 | 3.219 | 0.1875 | 0.2500 | front | x_from_labium = labium_to_foot * 2^(-offset_st/12); tune upward by enlarging |
| KAV-GS3-5H | Fipple Kaval | 2 | 3 | 246.942 | 24.808 | 4.694 | 0.1875 | 0.2500 | front | x_from_labium = labium_to_foot * 2^(-offset_st/12); tune upward by enlarging |
| KAV-GS3-5H | Fipple Kaval | 3 | 6 | 293.665 | 20.861 | 8.641 | 0.2188 | 0.3000 | front | x_from_labium = labium_to_foot * 2^(-offset_st/12); tune upward by enlarging |
| KAV-GS3-5H | Fipple Kaval | 4 | 7 | 311.127 | 19.69 | 9.812 | 0.2188 | 0.3000 | front | x_from_labium = labium_to_foot * 2^(-offset_st/12); tune upward by enlarging |
| KAV-GS3-5H | Fipple Kaval | 5 | 8 | 329.628 | 18.585 | 10.917 | 0.2188 | 0.3000 | front | x_from_labium = labium_to_foot * 2^(-offset_st/12); tune upward by enlarging |
| KAV-A3-5H | Fipple Kaval | 1 | 2 | 246.942 | 24.53 | 3.004 | 0.1875 | 0.2500 | front | x_from_labium = labium_to_foot * 2^(-offset_st/12); tune upward by enlarging |
| KAV-A3-5H | Fipple Kaval | 2 | 3 | 261.626 | 23.153 | 4.381 | 0.1875 | 0.2500 | front | x_from_labium = labium_to_foot * 2^(-offset_st/12); tune upward by enlarging |
| KAV-A3-5H | Fipple Kaval | 3 | 6 | 311.127 | 19.469 | 8.064 | 0.2188 | 0.3000 | front | x_from_labium = labium_to_foot * 2^(-offset_st/12); tune upward by enlarging |
| KAV-A3-5H | Fipple Kaval | 4 | 7 | 329.628 | 18.377 | 9.157 | 0.2188 | 0.3000 | front | x_from_labium = labium_to_foot * 2^(-offset_st/12); tune upward by enlarging |
| KAV-A3-5H | Fipple Kaval | 5 | 8 | 349.228 | 17.345 | 10.189 | 0.2188 | 0.3000 | front | x_from_labium = labium_to_foot * 2^(-offset_st/12); tune upward by enlarging |
| KAV-B3-5H | Fipple Kaval | 1 | 2 | 277.183 | 22.164 | 2.714 | 0.1875 | 0.2500 | front | x_from_labium = labium_to_foot * 2^(-offset_st/12); tune upward by enlarging |
| KAV-B3-5H | Fipple Kaval | 2 | 3 | 293.665 | 20.92 | 3.958 | 0.1875 | 0.2500 | front | x_from_labium = labium_to_foot * 2^(-offset_st/12); tune upward by enlarging |
| KAV-B3-5H | Fipple Kaval | 3 | 6 | 349.228 | 17.591 | 7.287 | 0.2188 | 0.3000 | front | x_from_labium = labium_to_foot * 2^(-offset_st/12); tune upward by enlarging |
| KAV-B3-5H | Fipple Kaval | 4 | 7 | 369.994 | 16.604 | 8.274 | 0.2188 | 0.3000 | front | x_from_labium = labium_to_foot * 2^(-offset_st/12); tune upward by enlarging |
| KAV-B3-5H | Fipple Kaval | 5 | 8 | 391.995 | 15.672 | 9.206 | 0.2188 | 0.3000 | front | x_from_labium = labium_to_foot * 2^(-offset_st/12); tune upward by enlarging |
| KAV-C4-5H | Fipple Kaval | 1 | 2 | 293.665 | 20.455 | 2.505 | 0.1875 | 0.2500 | front | x_from_labium = labium_to_foot * 2^(-offset_st/12); tune upward by enlarging |
| KAV-C4-5H | Fipple Kaval | 2 | 3 | 311.127 | 19.307 | 3.653 | 0.1875 | 0.2500 | front | x_from_labium = labium_to_foot * 2^(-offset_st/12); tune upward by enlarging |
| KAV-C4-5H | Fipple Kaval | 3 | 6 | 369.994 | 16.235 | 6.725 | 0.2188 | 0.3000 | front | x_from_labium = labium_to_foot * 2^(-offset_st/12); tune upward by enlarging |
| KAV-C4-5H | Fipple Kaval | 4 | 7 | 391.995 | 15.324 | 7.636 | 0.2188 | 0.3000 | front | x_from_labium = labium_to_foot * 2^(-offset_st/12); tune upward by enlarging |
| KAV-C4-5H | Fipple Kaval | 5 | 8 | 415.305 | 14.464 | 8.496 | 0.2188 | 0.3000 | front | x_from_labium = labium_to_foot * 2^(-offset_st/12); tune upward by enlarging |
| KAV-A3-7H | Fipple Kaval | 1 | 2 | 246.942 | 30.097 | 3.686 | 0.1875 | 0.2500 | front | x_from_labium = labium_to_foot * 2^(-offset_st/12); tune upward by enlarging |
| KAV-A3-7H | Fipple Kaval | 2 | 3 | 261.626 | 28.408 | 5.375 | 0.1875 | 0.2500 | front | x_from_labium = labium_to_foot * 2^(-offset_st/12); tune upward by enlarging |
| KAV-A3-7H | Fipple Kaval | 3 | 4 | 277.183 | 26.814 | 6.969 | 0.2188 | 0.3000 | front | x_from_labium = labium_to_foot * 2^(-offset_st/12); tune upward by enlarging |
| KAV-A3-7H | Fipple Kaval | 4 | 6 | 311.127 | 23.888 | 9.895 | 0.2188 | 0.3000 | front | x_from_labium = labium_to_foot * 2^(-offset_st/12); tune upward by enlarging |
| KAV-A3-7H | Fipple Kaval | 5 | 7 | 329.628 | 22.547 | 11.236 | 0.2188 | 0.3000 | front | x_from_labium = labium_to_foot * 2^(-offset_st/12); tune upward by enlarging |
| KAV-A3-7H | Fipple Kaval | 6 | 8 | 349.228 | 21.282 | 12.501 | 0.2188 | 0.3000 | front | x_from_labium = labium_to_foot * 2^(-offset_st/12); tune upward by enlarging |
| KAV-A3-7H | Fipple Kaval | 7 | 9 | 369.994 | 20.088 | 13.696 | 0.2188 | 0.3000 | front | x_from_labium = labium_to_foot * 2^(-offset_st/12); tune upward by enlarging |
| KAV-AS3-7H | Fipple Kaval | 1 | 2 | 261.626 | 28.344 | 3.471 | 0.1875 | 0.2500 | front | x_from_labium = labium_to_foot * 2^(-offset_st/12); tune upward by enlarging |
| KAV-AS3-7H | Fipple Kaval | 2 | 3 | 277.183 | 26.753 | 5.062 | 0.1875 | 0.2500 | front | x_from_labium = labium_to_foot * 2^(-offset_st/12); tune upward by enlarging |
| KAV-AS3-7H | Fipple Kaval | 3 | 4 | 293.665 | 25.251 | 6.563 | 0.2188 | 0.3000 | front | x_from_labium = labium_to_foot * 2^(-offset_st/12); tune upward by enlarging |
| KAV-AS3-7H | Fipple Kaval | 4 | 6 | 329.628 | 22.496 | 9.318 | 0.2188 | 0.3000 | front | x_from_labium = labium_to_foot * 2^(-offset_st/12); tune upward by enlarging |
| KAV-AS3-7H | Fipple Kaval | 5 | 7 | 349.228 | 21.234 | 10.581 | 0.2188 | 0.3000 | front | x_from_labium = labium_to_foot * 2^(-offset_st/12); tune upward by enlarging |
| KAV-AS3-7H | Fipple Kaval | 6 | 8 | 369.994 | 20.042 | 11.773 | 0.2188 | 0.3000 | front | x_from_labium = labium_to_foot * 2^(-offset_st/12); tune upward by enlarging |
| KAV-AS3-7H | Fipple Kaval | 7 | 9 | 391.995 | 18.917 | 12.898 | 0.2188 | 0.3000 | front | x_from_labium = labium_to_foot * 2^(-offset_st/12); tune upward by enlarging |
| KAV-B3-7H | Fipple Kaval | 1 | 2 | 277.183 | 22.865 | 2.8 | 0.1875 | 0.2500 | front | x_from_labium = labium_to_foot * 2^(-offset_st/12); tune upward by enlarging |
| KAV-B3-7H | Fipple Kaval | 2 | 3 | 293.665 | 21.582 | 4.083 | 0.1875 | 0.2500 | front | x_from_labium = labium_to_foot * 2^(-offset_st/12); tune upward by enlarging |
| KAV-B3-7H | Fipple Kaval | 3 | 4 | 311.127 | 20.371 | 5.295 | 0.2188 | 0.3000 | front | x_from_labium = labium_to_foot * 2^(-offset_st/12); tune upward by enlarging |
| KAV-B3-7H | Fipple Kaval | 4 | 6 | 349.228 | 18.148 | 7.517 | 0.2188 | 0.3000 | front | x_from_labium = labium_to_foot * 2^(-offset_st/12); tune upward by enlarging |
| KAV-B3-7H | Fipple Kaval | 5 | 7 | 369.994 | 17.13 | 8.536 | 0.2188 | 0.3000 | front | x_from_labium = labium_to_foot * 2^(-offset_st/12); tune upward by enlarging |
| KAV-B3-7H | Fipple Kaval | 6 | 8 | 391.995 | 16.168 | 9.497 | 0.2188 | 0.3000 | front | x_from_labium = labium_to_foot * 2^(-offset_st/12); tune upward by enlarging |
| KAV-B3-7H | Fipple Kaval | 7 | 9 | 415.305 | 15.261 | 10.405 | 0.2188 | 0.3000 | front | x_from_labium = labium_to_foot * 2^(-offset_st/12); tune upward by enlarging |

## photo-shotlist.md

Project artifact.

# Photo Shotlist

Follow the repo-level photo pipeline style: real process photos replace concept placeholders as soon as shop work begins.

## P0 Fipple Head

- End mouth inlet before plug install.
- Removable flue plugs with shim labels.
- Side true sound window and splitting edge closeup.
- Tuner screenshot or phone photo during first tone.

## P1 Bodies

- Blank selection with grain orientation marked.
- Split blank or deep-bore setup.
- Routed/bored bore before glue-up.
- Hole template wrapped around body.
- First drilled undersized hole.
- Final tuned flute full length.

## Jointed/Double Options

- Tenon/socket before cork.
- Cork/ferrule fit closeup.
- Double-body temporary clamp test.
- Independent windways at the mouth end.

## Finished Portfolio

- Kaval and Alghosazi side by side.
- Player hand reach shot.
- Fipple head detail.
- Validation/tuning bench shot.

## risks.md

Project artifact.

# Risks

## Acoustic

- **Fipple/sound-window correction is unknown.** Test: build `P0-FIPPLE-HEAD`, record root prediction vs measured, and update `estimated_sound_window_correction_in`.
- **Hole positions are first-pass proportional.** Test: drill undersized and record before/after cents for every hole in `validation.csv`.
- **Double-drone windways may steal pressure from each other.** Test: record each windway alone and together; compare attack and cents drift.

## Structural

- **Long solid blanks can wander while drilling.** Test: bore scrap first and measure exit offset; use split-blank CNC if wander exceeds 0.050 in.
- **Two-piece joints can leak or crack.** Test: vacuum/leak check and dry assembly force check before finishing.
- **Splitting edge is fragile.** Test: inspect under magnification after each voicing change.

## Ergonomic

- **7-hole kaval lower holes may require base-of-finger coverage.** Test: paper wrap mockup before drilling final diameters.
- **Alghosazi thumb hole may not fit all hands.** Test: mark with tape, play air-grip, then drill undersized.

## Supply

- **Elder and locust blanks may be hard to source in required lengths.** Test: verify supplier stock before committing scale/key; use ash/maple/cherry for prototypes.
- **Ferrule dimensions may not match body OD.** Test: choose ferrule after body OD is turned, not before.

## Fit And Finish

- **Finish can clog the windway.** Test: mask windway and splitting edge; recheck attack after cure.
- **Cork compression changes with humidity.** Test: assemble/disassemble after overnight humidity change and record fit.

## sources.md

Project artifact.

# Sources And Provenance

## External Pages Checked

- Fujara Flutes Kaval page: https://www.fujaraflutes.com/moldavian-kaval-flutes
- Fujara Flutes Alghosazi page: https://www.fujaraflutes.com/alghosazi
- Flutopedia Native American flute tunings / Anasazi note: https://www.flutopedia.com/naf_tunings.htm

## Local Sources Used

- `../fujara/README.md`
- `../fujara/design-table/fujara_equations.md`
- `../fujara/CAD/fujara-body/G2Fujara_Assembly.SLDASM_dimensions.csv`
- `../drone-flutes/design.md`
- `../flutes/skills/parametric-design-table.md`
- `../pistalka/docs/build-packet/design.md`

## Source-Backed Facts Used

- The kaval reference page presents fipple-style kavals and gives 5-hole and 7-hole pitch sets.
- The same page documents examples in G#, A, B, C and a double Kaval/Kavalghoza drone concept.
- The Alghosazi reference page frames the instrument as an easier fipple adaptation of an Anasazi-style flute and notes the rear thumb-hole idea.
- Tony's fujara CAD records a fipple/flue plug system with narrow windway, removable plug logic, and splitting-edge KPI values.

## Assumptions Needing Prototype Data

- Exact fipple sound-window end correction.
- Final hole diameters and undercutting.
- Alghosazi mode preference after listening/playing.
- Joint effect on tuning and response.

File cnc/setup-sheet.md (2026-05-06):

# CNC / Manufacturing Setup Sheet

- Packet: `.`
- Family: `woodwind`
- Generated: 2026-05-05
- Machine note: Maker Nexus/home shop; verify exact machine before CAM.

## Assumptions

- This is a pre-CAM operation graph, not verified G-code.
- Verify feeds, speeds, work envelope, hold-down, and tool clearance at the machine.
- Run air-cut or simulation before cutting instrument material.

## Operation Graph

### OP-010 - Review design package and mark datums

- Machine: Bench
- Tool: Calipers, square, marking knife, center punch
- Workholding: Flat bench, drawing packet
- Datum: Primary centerline / face A
- Inputs: design.md, drawing-brief.md, cut-list.csv
- Outputs: shop-marked blank, datum checklist
- Checks:
  - All stock dimensions exceed finished dimensions plus allowance
  - Units match drawings

### OP-110 - Prepare bore blank

- Machine: Table saw / jointer / planer
- Tool: Rip blade, jointer knives, planer
- Workholding: Push blocks, featherboard
- Datum: Face A and centerline
- Inputs: cut-list.csv
- Outputs: square bore blank
- Checks:
  - Blank straightness checked
  - Grain direction marked

### OP-210 - Create bore

- Machine: Lathe or CNC router
- Tool: Long brad-point bit, reamer, or ball/end mill for split blank
- Workholding: Tailstock vise/carrier or flip jig with datum pins
- Datum: Centerline A-B
- Inputs: drawing-brief.md, family-spec.csv
- Outputs: bored or routed body half
- Checks:
  - Bore wander checked on scrap
  - Bore diameter measured at both ends
- Notes: Use the deep-bore technique reference when the bore is long and straight.

### OP-310 - Cut tone features

- Machine: CNC router / drill press / laser template
- Tool: 1/8 in upcut spiral, brad-point bits, or printed drill guide
- Workholding: V-block, centerline fence, registration pins
- Datum: Embouchure end datum
- Inputs: scale table, drawing-brief.md
- Outputs: tone holes / windows
- Checks:
  - Hole spacing matches scale table
  - Undercut/tuning allowance left

### OP-900 - Validation and tuning pass

- Machine: Bench
- Tool: Chromatic tuner, calipers, scale, recording device
- Workholding: Padded bench
- Datum: Same acoustic datum used in design.md
- Inputs: validation.csv, finished part
- Outputs: updated validation.csv, process photo
- Checks:
  - Measured frequency recorded
  - Cents error computed
  - Tuning trim notes written

## Release Checks

- [ ] Every operation has a datum and workholding method.
- [ ] Every tool has a real machine available or an escalation note.
- [ ] All tuning-critical features include trim allowance.
- [ ] Validation.csv receives measured data after the first prototype.

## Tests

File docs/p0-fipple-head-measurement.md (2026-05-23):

# P0 Fipple Head Measurement Procedure

## Purpose

Build `P0-FIPPLE-HEAD` before committing a full kaval or Alghosazi body. The goal is to measure whether the end mouth inlet, internal windway, true side sound window, and splitting edge produce a stable tone, then back-solve the sound-window correction that the current hole schedules only estimate.

## Geometry Authority

- Measured: none yet in this repository.
- Inferred: starter windway/window values from Tony's fujara-style CAD notes and source-observed flute lengths.
- Unknown: final sound-window correction, production plug setting, final hole centers, and final hole diameters.

Generated images and SVG previews are layout aids. Fabrication authority comes from the workbook, `family-spec.csv`, `hole-schedule.csv`, CAD/design-table files, and future measured P0 rows.

## Build Setup

1. Use a scrap block or short split-blank section with a 0.875 in bore or half-bore test channel.
2. Mark the bore centerline, labium/splitting-edge datum, and top-to-window datum.
3. Cut the end mouth inlet and fit a removable flue plug.
4. Prepare plug shim trials at 0.033, 0.038, and 0.045 in windway height.
5. Start with a 0.320 in long by 0.500 in wide side sound window.
6. Keep the splitting-edge offset in the 0.005-0.015 in starter range.

## Measurement Pass

For each trial, change only one variable and log:

- plug shim height;
- window length and width;
- splitting-edge offset;
- bore ID and labium-to-foot length;
- temperature and relative humidity;
- measured root pitch from a tuner;
- attack quality, choking, overblow behavior, and recorder/phone audio file name.

## Back-Solve

Use the first stable tone to compute:

```text
L_eff_measured = c / (2 * measured_root_hz)
foot_end_correction = 0.6 * bore_radius
sound_window_correction = L_eff_measured - labium_to_foot - foot_end_correction
```

Record the result in `sound-window-correction-log.csv`. If the correction shifts any hole center by more than 0.100 in, update the workbook and regenerate `hole-schedule.csv`, `kaval-hole-schedule.csv`, and `alghosazi-hole-schedule.csv`.

## Promotion Gate

Do not mark the packet L2, build-ready, validated, or production-ready until the P0 log contains measured geometry, measured pitch, environment, and the resulting correction. Until then the packet remains `L1_packet` with measurement-required gates.

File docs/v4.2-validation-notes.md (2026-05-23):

# v4.2 Validation Notes

The packet intentionally does not apply Tony's Native American flute K2 correction table to this head. These instruments use a fujara-style true sound window and internal flue, so the sound-window correction must be measured.

Measured, inferred, and unknown geometry are separated as follows:

- Measured: none yet for the P0 fipple head in this repository.
- Inferred: fujara-style windway/window starter dimensions and source-observed body lengths.
- Unknown: the actual sound-window correction, final hole perturbation, and production-ready fipple setting.

Before final CAD:

1. Build `P0-FIPPLE-HEAD` from scrap or a short matching-bore tile.
2. Record the root pitch of an unholed body or matched test channel with temperature/RH.
3. Back-solve the sound-window correction with `L_eff = c/(2 * measured_root_hz)` and `sound_window_correction = L_eff - labium_to_foot - foot_end_correction`.
4. Record the result in `sound-window-correction-log.csv`.
5. Update `Kaval-Alghosazi-Design.xlsx`.
6. Regenerate `hole-schedule.csv` if offsets move more than 0.100 in.
7. Keep readiness at `L1_packet` until the measured correction and tuning rows exist.

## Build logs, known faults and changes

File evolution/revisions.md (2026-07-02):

# Revision Register — kaval-alghosazi-flutes

| Rev | Date | Parent | Delta | Downstream artifacts invalidated |
| --- | --- | --- | --- | --- |
| A | 2026-07-01 | — | Stage 0 intake of current masters (cad/kaval_alghosazi_master.scad + cad/kaval_alghosazi_body.scad + Kaval-Alghosazi-Design.xlsx + existing wolfram/kaval-alghosazi-flutes-wolfram-model.wl). README status normalized from prose-only "## Status" section to a proper `**Status:**` line (L1 concept packet, no level change). | none (no alpha/beta/production artifacts exist yet) |

Stage 0 only. Gate A has not been run; no Alpha compiles, vendor quotes, or production lock exist for this product. P0 fipple-head measurement remains the blocking gate for any promotion beyond L1_packet.

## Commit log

2026-05-20 Add P0 fipple measurement loop (#3)
    * Add P0 fipple measurement loop
    * Tighten hole-schedule wording: 'measured from' → 'computed from' (pre-P0)
    ---------
    [alghosazi-hole-schedule.csv, hole-schedule.csv, kaval-hole-schedule.csv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]
2026-05-29 Add sound-window correction model and effective_length column (Refs #1) (#4)
    Adds docs/sound-window-correction-model.md: acoustic back-solve derivation
    for KAV-A3-5H (+43 mm / +1.69 in) and ALG-AS3-J2 (+44.5 mm / +1.75 in),
    both marked model estimates pending P0 fipple-head measurement.
    Adds MODEL-KAV-A3 and MODEL-ALG-AS3 rows to sound-window-correction-log.csv
    with model_estimate_pending_P0 status.
    Adds effective_length_correction_mm column to hole-schedule.csv;
    all rows populated with pending_measurement. No hole positions change.
    [hole-schedule.csv, sound-window-correction-log.csv]
2026-05-30 v5-migrate(kaval-alghosazi-flutes): register + mcp-log + status (Refs instrument-maker#184) (#5)
    [visual-output-register.csv]
2026-05-31 wolfram-rename(kaval-alghosazi-flutes): unique {slug}-starter.wl + dedupe + ref fixes (cloud-sync naming) (#7)
    [visual-output-register.csv]
2026-05-31 Add image-gen concept prompt; wire explorer images
2026-06-21 Wire 3 rendered concept image(s) into explorer gallery
2026-07-02 V5 packet refresh: status line format fix, provenance, evolution intake
    Validator: python3 validate_v5_packet.py . --slug kaval-alghosazi-flutes -> 1 failure -> 0 failures, 10 pre-existing warnings unchanged (all pending_measurement authority WARNs). Added a proper "**Status:** L1 concept packet" line (prior README had only a prose "## Status" section with no parseable Status: line); no level change. Both existing cad/kaval_alghosazi_master.scad and cad/kaval_alghosazi_body.scad kept as-is, render-checked (openscad -o STL, exit 0 for both). Existing wolfram/kaval-alghosazi-flutes-wolfram-model.wl kept as-is. Added evolution/ Stage 0 intake.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
